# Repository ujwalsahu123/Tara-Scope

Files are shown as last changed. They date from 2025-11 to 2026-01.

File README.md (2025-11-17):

# Stargazer
Just for fun .

most people are too buys in this world and they dont see up the sky , ignore the true reality . 
i felt the same and dived into whats beyond the sky , wanna make something to solve the problem i faced . 
as a beginner in stargazing its very hard to do it . 
there is no cheap and quick thing which can be infomative and fun . 
sterallium and night sky are great , but they are not enough . 

The stargazer is device which uses a green laser to point to any celestial object selected by the user. you just need to install stellarium and select an object . the device will automatically point the lazer to it . dosent matter what your location , time , device orientation is .             (credits-jjrobots) 
Its small , cheap and can unlock the universe for you .

An automatic stargazing device is a tool that helps you easily find and track stars and other celestial objects. It uses motors to move a laser pointer or telescope to the exact position of a star based on your location and the current time. Sensors on the device ensure accurate pointing and tracking, so you can enjoy a clear view of the night sky without manually searching for objects.
<hr>
IDEA DEMO Video : <br>
https://youtube.com/shorts/w3IwdKpvQVA?si=-Li4YI_Lc3XkKAI4   <br>
https://youtu.be/OUAh3qONevA?si=fbP-pA_Mn6YwoY1l      
<hr>
i will try to post the updates (as files) . 

@ components -
arduino uno
stepper motor & drivers *3
bmp module 
mpu9250 
lazer pointer 

@ working -

   Input Location:
You start by inputting your location's latitude, longitude, and altitude into the system. This information helps the device understand where you are on Earth.
   
   Calculate Star Position:
The device uses astronomical algorithms to calculate the current position of the star you want to observe. It considers the date, time, and your location to determine the star's azimuth (horizontal angle) and altitude (vertical angle) in the sky.

  Sensor Data:
The stargazer uses an MPU9250 sensor, which has a magnetometer, gyroscope, and accelerometer. These sensors help determine the device's orientation (roll, pitch, and yaw) in real-time.

  Motor Control:
The device has two stepper motors:
One motor adjusts the azimuth (horizontal angle).
The other motor adjusts the altitude (vertical angle).
The motors move the laser pointer or telescope until the sensor readings match the calculated azimuth and altitude for the target star.
(using 3rd motor for z axis will also be great , but its not mandatory) . 

  Automatic Alignment:
The device uses the sensor data to continuously adjust the motors and keep the pointer aligned with the star. This ensures that the star remains in view, even if there are slight movements or changes.

check out this youtube website related to the project 
https://youtu.be/4PSazYw4XaM?si=X3MrnupO3QnW7joi
iit guy vedio link . 
ardunio project website link.

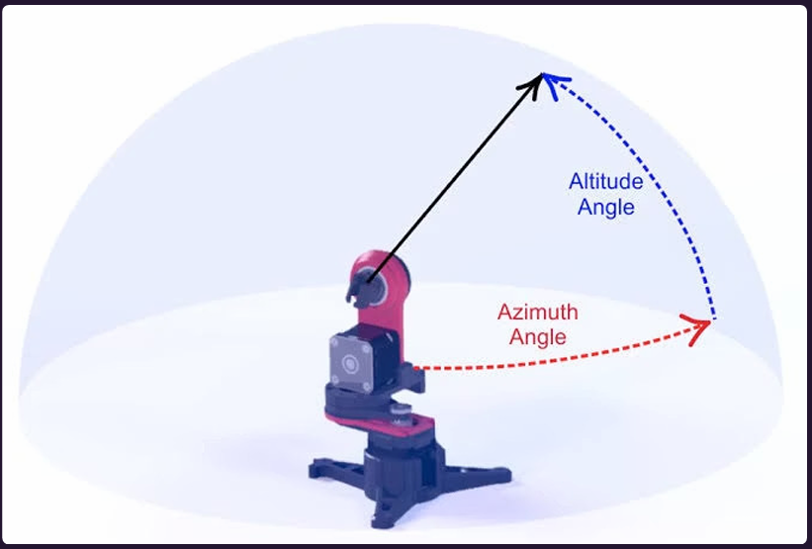
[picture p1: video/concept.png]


archives :
 
Hi guys , i am ujwal sahu , 21 yrs old , studying bachelors in AI form india   .
i am a beginner in stargazing and i was also making the same project as the startracker (the laser one) that you guys are making . 

I red the ( new version of startracker page) blog and its nice .
I think that the vision is exciting and creating a device which connect the space with a beginner with zero friction and affordability is great , though i think you guys are not headed in the right direction . 

lets talk from the bottom up - There are many many people who want to know about the space and not just fiction movies but really want to know about the reality of this world and who we are (not just the daily life we live ) . people forget that we live on a circular planet and there are millions of those and many other exciting things beyond the sky .  mostly every kid wants to become a astronaut , and they are super excited to explore this mysterious world but most dreams die because there is no one to tell them about these things . i myself when wanted to explore the sky , do stargazing , know about the stars above me - it was very difficult , a telescope is very expensive to buy and then also you have to learn about all the stargazing things . i had a green laser so i used to point to the stars and it made me feel like i have the power to touch the stars using the laser . i explored more and got to know about stellarium app and it was really helpful for me to do stargazing and i pointed my laser to the star using that and then i thought to make it automatic => so a device which can directly point to the star that are above me right now and also give me informoation about that and  hence now i am making that device . 
(tip - for sensor using mpu9250 is better , and all 3 axis matters ( yaw ,pitch ,roll) ).

Now if we take a step back and look then this device sucks ( a laser , are you serious ! , it can be illegal ) . and thats why you guys pivoted and made the starpointer form a laser pointing device to a mount for astrophotography  and thats why i said that you guys were not headed in the right direction . 

I think there is a real gap between the consumer who wants to do stargazing and unlock the universe .  
i know stellarium solves this problem , but still i dont think it connects people and excite them . it doesnt  provide much information and its not frictionless , etc . 
I dont know what to make which can solve this gap , which will be a great product . ( making a goto mount with cheap telescope and a better ai guide app which can walk you though the sky thats above you right now and tell facts and exciting thing about the objects and in the same time pointing the telescope to that object .   like a real human stargazing guide ) .  

I want to deep dive in this problem and i want to make something great .
i want to work with you guys .

please share your thoughts on this . 
Thank you .

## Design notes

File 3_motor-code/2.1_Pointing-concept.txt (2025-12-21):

// so we want to make a .ino code which takes alt az and moves motor to achive the RPY to ALt Az. 
// 2 din ka kam hai . - just use the SF code & the logic part sooch lay of how pointing and motor movement ( parallel ) ,  etc stuff ...  and mix karde 
// and then test out karle -> Run the ai_guide wala code to get the alt az and send alt az to arduino (manually) . and see the pointing accracy / error. 

0. make the flowchart - after reading this full info , and old code downside.
1. get the sf_code.ino (which geives the RPY using raw values)
2 see below code for knowing the logic of pointing. (alt az ayga , alt_higher = alt + 0.1 , alt_lower = alt - 0.1 , ..   use delay_speed for faster and slower range )
3 do it for 2 motors ( think how - parallel kaise hoga ?  - read - then motor1 - then motor2 - read .   or like - read - non blocking motor1, ... ? idk )
4 also the SF part is time taking so - we can run the SF code in the Parallel, and just read the latest value and move the motors as per that. 

default function - when pressed 0 or 0 0 then it goes to 0 position. 
// or we can do like - it points and after both motors reached - it calls the laser (fade) and then after laser turned off it goes to default mode and points - 0 , 0 
// and after another alt az we get - it points - turns on laser - comes back to 0,0 .

// basically - we use the SF_code.ino for getting the Rpy from sensor . and we use the Pointing_concept -> which is ek ALT Az diya jaygaa
// and arduino has to catch it. and then range -> Alt_low , Alt_high. and then there is a logic -> read the Pitch and if pitch < Alt_low then move ALT motor clockwise until 
// its in range. so basically the motor move until it reach the target posi. 
// and there are other stuff like - move 1 step when closer , and parallel move both the motors and etc stuff - Run the RPY in parallel function , and in the main function just get the RPY value and make the motors move as per that . 
// or write the RPY calculation function in the main code . idk which is better. need to think.  

// so the Full-motor-code has 2 parts -> SF part . and logic part. 
// the logic part is given below - in flowchart. 
// the SF part is v.imp . so write a SF_code.ino - which simply gets the raw sensors values and does SF and gives RPY. 

Checkout the Arduino.txt file - it has some logic. ..... *******************

// also need to think when will the laser be on -> after target reached , or when pressed space.

// if near then less step move , if far then more step move.
// and it contineaouly iterates .

// and its like a range - (it dosent directly point to 0 deg)
// its like we move the motor to run till it achives a range of (-0.1 to 0.1)

// parallel how motor...

// i think we need to manually hardcode the offset values of mag in the .ino code - after doing mag calib. 
// and acc , gyro ka too direct hardcoded rahega. 

// motor concept -> 

// Alt Az ayga , and the range will become 
// int range = 0.1
// ALT_LOWER =  ALT - range
// ALT_UPPER =  ALT + range
// AZ_LOWER =  AZ - range
// AZ_UPPER =  AZ + range

// so if the ALT = 45.5 then the rangle will be 45.4 to 45.6. and if the sensor pitch is beween that range then it will not move.

// and after the both the targed range is achieved , the laserfade() function will be called to turn on the laser.

// entire flow likh ------------------------------------------
# ..... read sensor ,  parallel motor move , laser point , ......

contineaouly RPY print hoga in terminal so i can know . 

// for parallel motor movement - use cheapstepper ka .newmove(step) function . which is a non-blocking function. 

so  -> loop{

    read sensr value and use SF to get RPY

    if (pitch > alt_higer)
        motorA.newmove(1)
    else if (pitch < alt_lower)
        motorA.newmove(-1)
    else
        motorA.newmove(0)
    
    same for yaw.

    .run()
}

// so it reads RPY then both motors by one step. 

// so here again and again if we read the RPY after every loop then not good. 
// insted we can make another function paralley to calculate RPY. 
// idk if this is good or bad. need to think . since this above code is also looks good. 

old code - MPU wala ---------------------------------------------------------------------------------------

#include <Wire.h>
#include <MPU6050_6Axis_MotionApps20.h>
#include <AccelStepper.h>

// Motor Pins for ULN2003 driver
#define IN1 2
#define IN2 3
#define IN3 4
#define IN4 5

// Target Roll Range
#define TARGET_MIN_ROLL 0.0  // Minimum acceptable roll value
#define TARGET_MAX_ROLL 10.0  // Maximum acceptable roll value

// Speed Adjustment Variables
#define NORMAL_SPEED 400        // Normal speed when roll is far from target range
#define FIRST_SLOW_RANGE 20.0   // Range for slower speed (20 degrees)
#define FIRST_SLOW_RANGE_VAL 10 // Speed value for first slow range
#define SECOND_SLOW_RANGE 10.0  // Range for very slow speed (10 degrees)
#define SECOND_SLOW_RANGE_VAL 2 // Speed value for second slow range

// Initialize stepper motor and MPU
AccelStepper stepper(AccelStepper::FULL4WIRE, IN1, IN3, IN2, IN4);
MPU6050 mpu;

// Global variables
bool dmpReady = false;
uint8_t devStatus;
uint16_t packetSize;
uint8_t fifoBuffer[64];
float currentRoll = 0.0;

// Initialize MPU and Stepper
void setup() {
  Serial.begin(115200);
  Wire.begin();

  // MPU setup
  mpu.initialize();
  devStatus = mpu.dmpInitialize();
  if (devStatus == 0) {
    mpu.setDMPEnabled(true);
    dmpReady = true;
    packetSize = mpu.dmpGetFIFOPacketSize();
    Serial.println("DMP initialized successfully");
  } else {
    Serial.print("DMP initialization failed with code ");
    Serial.println(devStatus);
  }

  // Stepper motor setup
  stepper.setMaxSpeed(1000); // Set maximum motor speed
  stepper.setSpeed(NORMAL_SPEED);     // Set initial motor speed
}

// Function to read roll from MPU6050
void readRoll() {
  if (!dmpReady) return;

  // Check if there's data available in the FIFO buffer
  while (mpu.getFIFOCount() >= packetSize) {
    mpu.getFIFOBytes(fifoBuffer, packetSize);

    Quaternion q;
    VectorFloat gravity;
    float ypr[3];  // Array to hold yaw, pitch, and roll values
    mpu.dmpGetQuaternion(&q, fifoBuffer);
    mpu.dmpGetGravity(&gravity, &q);
    mpu.dmpGetYawPitchRoll(ypr, &q, &gravity);

    // Convert roll to degrees
    currentRoll = ypr[2] * 180.0 / PI;  // ypr[2] is the roll value
  }
}

// Function to adjust motor direction and speed based on roll
void adjustMotorToRollRange() {
  if (currentRoll < TARGET_MIN_ROLL - FIRST_SLOW_RANGE || currentRoll > TARGET_MAX_ROLL + FIRST_SLOW_RANGE) {
    // Roll is far from target range, normal speed (400)
    stepper.setSpeed(currentRoll < TARGET_MIN_ROLL ? NORMAL_SPEED : -NORMAL_SPEED); // Normal speed
    Serial.print("Roll: ");
    Serial.print(currentRoll);
    Serial.println(" (Normal Speed)");
  } else if (((currentRoll >= (TARGET_MIN_ROLL - FIRST_SLOW_RANGE)) && (currentRoll < (TARGET_MIN_ROLL - SECOND_SLOW_RANGE))) ||
             ((currentRoll > (TARGET_MAX_ROLL + SECOND_SLOW_RANGE)) && (currentRoll <= (TARGET_MAX_ROLL + FIRST_SLOW_RANGE)))) {
    // Roll is closer to target range, medium speed (10)
    stepper.setSpeed(currentRoll < TARGET_MIN_ROLL ? FIRST_SLOW_RANGE_VAL : -FIRST_SLOW_RANGE_VAL); // Medium speed
    Serial.print("Roll: ");
    Serial.print(currentRoll);
    Serial.println(" (Medium Speed)");
  } else if (((currentRoll >= (TARGET_MIN_ROLL - SECOND_SLOW_RANGE)) && (currentRoll <= TARGET_MIN_ROLL))  ||
             ((currentRoll <= (TARGET_MAX_ROLL + SECOND_SLOW_RANGE)) && (currentRoll >= TARGET_MAX_ROLL))) {
    // Roll is very close to the target range, very slow speed (1)
    stepper.setSpeed(currentRoll < TARGET_MIN_ROLL ? SECOND_SLOW_RANGE_VAL : -SECOND_SLOW_RANGE_VAL); // Very slow speed
    Serial.print("Roll: ");
    Serial.print(currentRoll);
    Serial.println(" (Very Slow Speed)");
  } else {
    // Roll is within target range, stop motor
    stepper.setSpeed(0); // Stop
    Serial.print("Roll: ");
    Serial.print(currentRoll);
    Serial.println(" (Stop)");
  }
}

// Main loop
void loop() {
  // Continuously read roll from MPU
  readRoll();

  // Adjust motor movement based on roll
  adjustMotorToRollRange();

  // Run the motor at the determined speed
  stepper.runSpeed();
}

---------------------------------------------------------------------------------------
ok so in the above code i had use mpu sensor , and fastaccel code , but  i next time i want to use some other sensor , but this concept of the code is very important . so can you please remove all the mpu sensor part . and instead you can leave a comment like get yaw data .... etc . 

(so here , its the logic code , wihout the mpu par )

#include <AccelStepper.h>

// Motor Pins for ULN2003 driver
#define IN1 2
#define IN2 3
#define IN3 4
#define IN4 5

// Target Roll Range
#define TARGET_MIN_ROLL 0.0  // Minimum acceptable roll value
#define TARGET_MAX_ROLL 10.0 // Maximum acceptable roll value

// Speed Adjustment Variables
#define NORMAL_SPEED 400        // Normal speed when roll is far from target range
#define FIRST_SLOW_RANGE 20.0   // Range for slower speed (20 degrees)
#define FIRST_SLOW_RANGE_VAL 10 // Speed value for first slow range
#define SECOND_SLOW_RANGE 10.0  // Range for very slow speed (10 degrees)
#define SECOND_SLOW_RANGE_VAL 2 // Speed value for second slow range

// Initialize stepper motor
AccelStepper stepper(AccelStepper::FULL4WIRE, IN1, IN3, IN2, IN4);

// Global variables
float currentRoll = 0.0; // Variable to store the roll value

// Initialize Stepper
void setup() {
  Serial.begin(115200);

  // Stepper motor setup
  stepper.setMaxSpeed(1000); // Set maximum motor speed
  stepper.setSpeed(NORMAL_SPEED); // Set initial motor speed

  Serial.println("System initialized. Waiting for sensor data...");
}

// Function to update the roll value
void updateRoll() {
  // Replace the following line with the logic to get roll (or yaw) data from your sensor
  // Example: currentRoll = getYawFromSensor(); or currentRoll = readSensorRoll();
  // Ensure the roll value is in degrees.
  
  // Placeholder for testing
  currentRoll = random(-30, 30); // Replace with actual sensor logic
}

// Function to adjust motor direction and speed based on roll
void adjustMotorToRollRange() {
  if (currentRoll < TARGET_MIN_ROLL - FIRST_SLOW_RANGE || currentRoll > TARGET_MAX_ROLL + FIRST_SLOW_RANGE) {
    // Roll is far from target range, normal speed
    stepper.setSpeed(currentRoll < TARGET_MIN_ROLL ? NORMAL_SPEED : -NORMAL_SPEED);
    Serial.print("Roll: ");
    Serial.print(currentRoll);
    Serial.println(" (Normal Speed)");
  } else if (((currentRoll >= (TARGET_MIN_ROLL - FIRST_SLOW_RANGE)) && (currentRoll < (TARGET_MIN_ROLL - SECOND_SLOW_RANGE))) ||
             ((currentRoll > (TARGET_MAX_ROLL + SECOND_SLOW_RANGE)) && (currentRoll <= (TARGET_MAX_ROLL + FIRST_SLOW_RANGE)))) {
    // Roll is closer to target range, medium speed
    stepper.setSpeed(currentRoll < TARGET_MIN_ROLL ? FIRST_SLOW_RANGE_VAL : -FIRST_SLOW_RANGE_VAL);
    Serial.print("Roll: ");
    Serial.print(currentRoll);
    Serial.println(" (Medium Speed)");
  } else if (((currentRoll >= (TARGET_MIN_ROLL - SECOND_SLOW_RANGE)) && (currentRoll <= TARGET_MIN_ROLL))  ||
             ((currentRoll <= (TARGET_MAX_ROLL + SECOND_SLOW_RANGE)) && (currentRoll >= TARGET_MAX_ROLL))) {
    // Roll is very close to the target range, very slow speed
    stepper.setSpeed(currentRoll < TARGET_MIN_ROLL ? SECOND_SLOW_RANGE_VAL : -SECOND_SLOW_RANGE_VAL);
    Serial.print("Roll: ");
    Serial.print(currentRoll);
    Serial.println(" (Very Slow Speed)");
  } else {
    // Roll is within target range, stop motor
    stepper.setSpeed(0);
    Serial.print("Roll: ");
    Serial.print(currentRoll);
    Serial.println(" (Stop)");
  }
}

// Main loop
void loop() {
  // Continuously update roll value from the sensor
  updateRoll();

  // Adjust motor movement based on roll
  adjustMotorToRollRange();

  // Run the motor at the determined speed
  stepper.runSpeed();
}

---------------------------------------------------------------------------------------
ok now can you make this same conectp and code for cheapstepper library instead of fastaccell

(so now gpt gave the code using cheapstepper.) but the logic can be imporved
instead of using the Rpm(speed) , we can move 1 step at a time and we will play with the delay speed . 
to make the speed - fast / slow . 

#include <CheapStepper.h>

// Motor Pins for ULN2003 driver
#define IN1 2
#define IN2 3
#define IN3 4
#define IN4 5

// Target Roll Range
#define TARGET_MIN_ROLL 0.0  // Minimum acceptable roll value
#define TARGET_MAX_ROLL 10.0 // Maximum acceptable roll value

// Speed Adjustment Variables
#define NORMAL_DELAY 2        // Normal speed delay (lower value = faster speed)
#define FIRST_SLOW_DELAY 10   // Medium speed delay
#define SECOND_SLOW_DELAY 30  // Very slow speed delay

// Initialize stepper motor
CheapStepper stepper(IN1, IN2, IN3, IN4);

// Global variables
float currentRoll = 0.0; // Variable to store the roll value
bool motorMoving = false;

// Initialize Stepper
void setup() {
  Serial.begin(115200);

  // Stepper motor setup
  stepper.setRpm(15); // Default RPM (can be adjusted dynamically later)

  Serial.println("System initialized. Waiting for sensor data...");
}

// Function to update the roll value
void updateRoll() {
  // Replace the following line with the logic to get roll (or yaw) data from your sensor
  // Example: currentRoll = getYawFromSensor(); or currentRoll = readSensorRoll();
  // Ensure the roll value is in degrees.

  // Placeholder for testing
  currentRoll = random(-30, 30); // Replace with actual sensor logic
}

// Function to adjust motor direction and speed based on roll
void adjustMotorToRollRange() {
  if (currentRoll < TARGET_MIN_ROLL - 20.0 || currentRoll > TARGET_MAX_ROLL + 20.0) {
    // Roll is far from target range, normal speed
    stepper.setRpm(30); // Set higher RPM for faster movement
    motorMoving = true;
    if (currentRoll < TARGET_MIN_ROLL) {
      stepper.moveDegreesCW(5); // Move clockwise
    } else {
      stepper.moveDegreesCCW(5); // Move counterclockwise
    }
    Serial.print("Roll: ");
    Serial.print(currentRoll);
    Serial.println(" (Normal Speed)");
  } else if (((currentRoll >= (TARGET_MIN_ROLL - 20.0)) && (currentRoll < (TARGET_MIN_ROLL - 10.0))) ||
             ((currentRoll > (TARGET_MAX_ROLL + 10.0)) && (currentRoll <= (TARGET_MAX_ROLL + 20.0)))) {
    // Roll is closer to target range, medium speed
    stepper.setRpm(10); // Set medium RPM for slower movement
    motorMoving = true;
    if (currentRoll < TARGET_MIN_ROLL) {
      stepper.moveDegreesCW(1); // Move clockwise slowly
    } else {
      stepper.moveDegreesCCW(1); // Move counterclockwise slowly
    }
    Serial.print("Roll: ");
    Serial.print(currentRoll);
    Serial.println(" (Medium Speed)");
  } else if (((currentRoll >= (TARGET_MIN_ROLL - 10.0)) && (currentRoll <= TARGET_MIN_ROLL)) ||
             ((currentRoll <= (TARGET_MAX_ROLL + 10.0)) && (currentRoll >= TARGET_MAX_ROLL))) {
    // Roll is very close to the target range, very slow speed
    stepper.setRpm(5); // Set very slow RPM for precise movement
    motorMoving = true;
    if (currentRoll < TARGET_MIN_ROLL) {
      stepper.moveStepsCW(1); // Very slow clockwise movement
    } else {
      stepper.moveStepsCCW(1); // Very slow counterclockwise movement
    }
    Serial.print("Roll: ");
    Serial.print(currentRoll);
    Serial.println(" (Very Slow Speed)");
  } else {
    // Roll is within target range, stop motor
    motorMoving = false;
    Serial.print("Roll: ");
    Serial.print(currentRoll);
    Serial.println(" (Stop)");
  }
}

// Main loop
void loop() {
  // Continuously update roll value from the sensor
  updateRoll();

  // Adjust motor movement based on roll
  adjustMotorToRollRange();

  // Allow the motor to complete the current step if moving
  if (motorMoving) {
    stepper.run();
  }
}

---------------------------------------------------------------------------------------

same as the above code - but for 2 motors - pitch and yaw . 

#include <CheapStepper.h>

// Motor Pins for Pitch (ULN2003 driver)
#define PITCH_IN1 2
#define PITCH_IN2 3
#define PITCH_IN3 4
#define PITCH_IN4 5

// Motor Pins for Yaw (ULN2003 driver)
#define YAW_IN1 6
#define YAW_IN2 7
#define YAW_IN3 8
#define YAW_IN4 9

// Target Ranges
#define TARGET_MIN_PITCH 0.0  // Minimum acceptable pitch value
#define TARGET_MAX_PITCH 10.0 // Maximum acceptable pitch value
#define TARGET_MIN_YAW 0.0    // Minimum acceptable yaw value
#define TARGET_MAX_YAW 10.0   // Maximum acceptable yaw value

// Initialize stepper motors
CheapStepper pitchMotor(PITCH_IN1, PITCH_IN2, PITCH_IN3, PITCH_IN4);
CheapStepper yawMotor(YAW_IN1, YAW_IN2, YAW_IN3, YAW_IN4);

// Global variables for sensor data
float currentPitch = 0.0;
float currentYaw = 0.0;

// Initialize Stepper
void setup() {
  Serial.begin(115200);

  // Motor setup
  pitchMotor.setRpm(15); // Default RPM for pitch motor
  yawMotor.setRpm(15);   // Default RPM for yaw motor

  Serial.println("System initialized. Waiting for sensor data...");
}

// Function to update pitch and yaw values
void updatePitchAndYaw() {
  // Replace these lines with the logic to get pitch and yaw data from your sensor
  // Example: currentPitch = getPitchFromSensor(); currentYaw = getYawFromSensor();

  // Placeholder for testing
  currentPitch = random(-30, 30); // Replace with actual sensor logic
  currentYaw = random(-30, 30);   // Replace with actual sensor logic
}

// Function to adjust pitch motor
void adjustPitchMotor() {
  if (currentPitch < TARGET_MIN_PITCH - 20.0 || currentPitch > TARGET_MAX_PITCH + 20.0) {
    // Far from target range, normal speed
    pitchMotor.setRpm(30);
    if (currentPitch < TARGET_MIN_PITCH) {
      pitchMotor.moveDegreesCW(5); // Move clockwise
    } else {
      pitchMotor.moveDegreesCCW(5); // Move counterclockwise
    }
    Serial.print("Pitch: ");
    Serial.print(currentPitch);
    Serial.println(" (Normal Speed)");
  } else if (abs(currentPitch - TARGET_MIN_PITCH) <= 10.0 || abs(currentPitch - TARGET_MAX_PITCH) <= 10.0) {
    // Close to target range, slow speed
    pitchMotor.setRpm(5);
    if (currentPitch < TARGET_MIN_PITCH) {
      pitchMotor.moveStepsCW(1); // Move very slowly clockwise
    } else {
      pitchMotor.moveStepsCCW(1); // Move very slowly counterclockwise
    }
    Serial.print("Pitch: ");
    Serial.print(currentPitch);
    Serial.println(" (Slow Speed)");
  } else {
    // Within range, stop motor
    Serial.print("Pitch: ");
    Serial.print(currentPitch);
    Serial.println(" (Stop)");
  }
}

// Function to adjust yaw motor
void adjustYawMotor() {
  if (currentYaw < TARGET_MIN_YAW - 20.0 || currentYaw > TARGET_MAX_YAW + 20.0) {
    // Far from target range, normal speed
    yawMotor.setRpm(30);
    if (currentYaw < TARGET_MIN_YAW) {
      yawMotor.moveDegreesCW(5); // Move clockwise
    } else {
      yawMotor.moveDegreesCCW(5); // Move counterclockwise
    }
    Serial.print("Yaw: ");
    Serial.print(currentYaw);
    Serial.println(" (Normal Speed)");
  } else if (abs(currentYaw - TARGET_MIN_YAW) <= 10.0 || abs(currentYaw - TARGET_MAX_YAW) <= 10.0) {
    // Close to target range, slow speed
    yawMotor.setRpm(5);
    if (currentYaw < TARGET_MIN_YAW) {
      yawMotor.moveStepsCW(1); // Move very slowly clockwise
    } else {
      yawMotor.moveStepsCCW(1); // Move very slowly counterclockwise
    }
    Serial.print("Yaw: ");
    Serial.print(currentYaw);
    Serial.println(" (Slow Speed)");
  } else {
    // Within range, stop motor
    Serial.print("Yaw: ");
    Serial.print(currentYaw);
    Serial.println(" (Stop)");
  }
}

// Main loop
void loop() {
  // Continuously update pitch and yaw values
  updatePitchAndYaw();

  // Adjust motor movement based on pitch and yaw
  adjustPitchMotor();
  adjustYawMotor();
}

---------------------------------------------------------------------------------------
---------------------------------------------------------------------------------------
---------------------------------------------------------------------------------------
---------------------------------------------------------------------------------------

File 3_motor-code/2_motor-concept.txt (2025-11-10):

// arduino code.txt may bhi hai ..
// star_pointing gpt chat. 

// if near then less step move , if far then more step move.
// and it contineaouly iterates .

// and its like a range - (it dosent directly point to 0 deg)
// its like we move the motor to run till it achives a range of (-0.1 to 0.1)

// parallel how motor...

// i think we need to manually hardcode the offset values of mag in the .ino code - after doing mag calib. 
// and acc , gyro ka too direct hardcoded rahega. 

// motor concept -> 

// Alt Az ayga , and the range will become 
// int range = 0.1
// ALT_LOWER =  ALT - range
// ALT_UPPER =  ALT + range
// AZ_LOWER =  AZ - range
// AZ_UPPER =  AZ + range

// so if the ALT = 45.5 then the rangle will be 45.4 to 45.6. and if the sensor pitch is beween that range then it will not move.

// and after the both the targed range is achieved , the laserfade() function will be called to turn on the laser.

// entire flow likh ------------------------------------------
# ..... read sensor ,  parallel motor move , laser point , ......

setOutputTorque(true)
Coils stay ON → motor locks position (useful when holding a laser steady) 
? idk to use this.  since we move motors as per sensors (consistently) and not just move some particular step and wait.

// for parallel motor movement - use cheapstepper ka .newmove(step) function . which is a non-blocking function. 

so  -> loop{

    read sensr value and use SF to get RPY

    if (pitch > alt_higer)
        motorA.newmove(1)
    else if (pitch < alt_lower)
        motorA.newmove(-1)
    else
        motorA.newmove(0)
    
    same for yaw.

    .run()
}

// so it reads RPY then both motors by one step. 

// so here again and again if we read the RPY after every loop then not good. 
// insted we can make another function paralley to calculate RPY. 
// idk if this is good or bad. need to think . since this above code is also looks good.

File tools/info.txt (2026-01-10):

TaraScope – Arduino CLI + Python Workflow Notes
==============================================

1) Install Arduino CLI (Windows 64-bit)
---------------------------------------
Download:
https://github.com/arduino/arduino-cli/releases

File:
arduino-cli_1.4.0_Windows_64bit.zip

Extract anywhere (example):
S:\ujwal sahu\Downloads\arduino-cli_1.4.0_Windows_64bit

Add the folder containing:
arduino-cli.exe
to **User Environment Variable → PATH**  (press win -> search Environment variable -> Advance -> Environment variable -> press PATH in user env variable -> Edit -> NEW -> paste the folder path in which .exe file is there -> ok , ok , ok .) ( do like this also next times for adding Env variable and also Restart vs code...)

Verify in CMD / PowerShell:
arduino-cli version

2) Initial Arduino CLI Setup in cmd
----------------------------
Generate config file:
arduino-cli config init

This creates:
C:\Users\<username>\AppData\Local\Arduino15\arduino-cli.yaml

Verify config:
arduino-cli config dump

3) Configure Arduino Libraries Location
---------------------------------------
Edit file:
C:\Users\<username>\AppData\Local\Arduino15\arduino-cli.yaml

Ensure this exists:  (path location in which the arudino libraries are there / so that we use that same libraries here also)
directories:
  user: S:\ujwal sahu\OneDrive\Documents\Arduino     

(This makes Arduino CLI use the SAME libraries as Arduino IDE)

4) Install Board Support in cmd (Arduino Uno / AVR)
--------------------------------------------
Update index:
arduino-cli core update-index

Install AVR core:
arduino-cli core install arduino:avr

5) Verify Arduino Connection in cmd
----------------------------
Plug Arduino Uno

Check port:
arduino-cli board list

Example output:
COM7  serial  Arduino Uno

6) Create upload.bat (Single Universal Uploader)
------------------------------------------------
Location:
TaraScope\tools\upload.bat

(put the parent folder in which the upload.bat is there (aka S:\ujwal sahu\...\TaraScope\tools ) -> to Environment varibale PATH so it can be run from ANY folder)

Usage:
upload uno COM7 115200 file.ino

Supports:
- Any folder
- Any .ino file
- Arduino Uno / Nano / etc
- Compile + Upload + Serial Monitor

7) upload.bat Features
----------------------
- Auto-detect sketch folder
- Fix Arduino requirement:
  (main .ino name == folder name)
- Uses Arduino IDE libraries
- Shows compile errors in terminal
- Opens Serial Monitor automatically

8) Compile + Upload from Anywhere
---------------------------------
Examples:

upload uno COM7 115200 TARA_SCOPE.ino

upload uno COM7 115200
"S:\ujwal sahu\Tara_Scope\1_calibration\4_final\1.1_Auto_calib.ino"

9) Python + Arduino Workflow
----------------------------
- Python sends commands via Serial
- Arduino performs calibration / sensor read
- Python stores results in offsets.txt
- Offsets sent back to Arduino on demand
- No auto-offset on boot (manual trigger with 'g')

10) Important Rules (Very Important)
------------------------------------
- .ino files must contain ONLY valid C/C++ code
- Notes / explanations MUST be in:
  - info.txt
  - README.md
  - comments (// or /* */)
- NEVER paste plain English into .ino without comments
- Arduino CLI is stricter than Arduino IDE

11) Final Command Summary
------------------------
Check version:
arduino-cli version

List boards:
arduino-cli board list

Upload from anywhere:
upload uno COM7 115200 file.ino

Status: ✔ WORKING
-----------------
Arduino CLI + Python + Calibration system is stable.

12) Installing Arduino Libraries (2 Ways)
-----------------------------------------

There are TWO ways to install Arduino libraries.
We are using WAY 1 (recommended).

-----------------------------------------
WAY 1 (Recommended – Uses Arduino IDE)
-----------------------------------------
This is what we are already doing.

Steps:
1. Open Arduino IDE
2. Go to:
   Sketch → Include Library → Manage Libraries
3. Search and install required libraries
   (example: SparkFun ISM330DHCX, CheapStepper, etc.)

Where libraries are stored:
S:\ujwal sahu\OneDrive\Documents\Arduino\libraries

Why this works:
- Arduino IDE and Arduino CLI share the SAME library folder
- No duplicate installs
- No version mismatch
- Arduino CLI automatically finds libraries

✔ This is the BEST and simplest method

-----------------------------------------
WAY 2 (CLI-only Method – Optional)
-----------------------------------------
Use this ONLY if you do NOT have Arduino IDE installed.

Example:
arduino-cli lib update-index
arduino-cli lib install "SparkFun 6DoF ISM330DHCX"
arduino-cli lib install "CheapStepper"

Libraries will still be installed into:
directories.user (from arduino-cli.yaml)

Downside:
- Harder to manage
- Library names must be exact
- Less visual control

-----------------------------------------
How to Verify Library Installation
-----------------------------------------
Run:
arduino-cli lib list

Or check folder:
S:\ujwal sahu\OneDrive\Documents\Arduino\libraries

-----------------------------------------
Important Rules for Libraries
-----------------------------------------
- Do NOT mix multiple library folders
- Do NOT copy libraries manually unless necessary
- Always include headers properly in .ino:
  #include <Wire.h>
  #include <SparkFun_ISM330DHCX.h>
- If compilation fails:
  → Check library name
  → Check library path
  → Check include order

Status:
✔ Library system is correctly configured
✔ Arduino IDE + Arduino CLI are fully synced

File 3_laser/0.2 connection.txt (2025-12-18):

there are many ways to make the LASER DRIVER

we can power the laser - directly by the arduino , or by external power supply - and use LM... to Step down the voltage to 3v or etc as per the laser . 

connetion option 1 -> using relay 

.... we can directly or using LM

......

connection option 2 -> using logic level mosfet

.... driectly or using LM

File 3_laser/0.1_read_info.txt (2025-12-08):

// 1) define the pin number 
// #define LASER_PIN 3, 5, 6, 9, 10, 11 (analog / PWM) 2, 3, 4, 7, 8, 12, 13 (digital)

// 2) in setup - set the pin mode to output . and set it low to start with laser off
// pinMode(LASER_PIN, OUTPUT);
// digitalWrite(LASER_PIN, LOW);

// 3) to turn on the laser at full intensity - set the pin high

//  digitalWrite(LASER_PIN, HIGH);  // (ON) Switch is ON thus the laser is ON (it will be ON until set off)
//  analogWrite(LASER_PIN, 0-255);  // (ON) controlled brightness (use a PWM digital pin) (it will be ON until set off)
//  digitalWrite(LASER_PIN, LOW);   // (OFF) so the Switch is now OFF and thus laser is OFF

// the PWM pins quickly turns the current on and off
// PWM doesn’t actually change the current level — the current is always 0% or 100%. It simply turns the power ON and OFF very quickly (hundreds of times per second), and the ratio of ON vs OFF time makes our eyes perceive different brightness levels.
// 20% duty -> 20% time on , 80% time off 

-----------------------------------------------INFO----------------------------------------------------

UNO vs ESP  - digital pins to use . 

## ⚙️ For **Arduino Uno:**

### 🔹 **Normal ON/OFF (digital control)**

You can use **any digital pin** for this.
✅ Recommended pins:

```
2, 3, 4, 7, 8, 12, or 13
```

➡️ Example:

```cpp
#define LASER_PIN 7
```

and use `digitalWrite(LASER_PIN, HIGH/LOW)` for full ON/OFF control.

---

### 🔸 **Brightness Control (PWM mode)**

PWM = analog-style brightness via fast ON/OFF switching.
Only certain pins on the Uno support this.

✅ PWM-capable pins:

```
3, 5, 6, 9, 10, 11
```

➡️ Example:

```cpp
#define LASER_PIN 9
```

and use `analogWrite(LASER_PIN, value);`
where `value` ranges from **0 (off)** to **255 (full brightness)**.

---

### ⚠️ **Note**

* The PWM pins usually have a **“~” (tilde symbol)** next to them on your Arduino board.
* Don’t use the same pin for both functions at once — just pick **one**:

  * Pin 7 → simple ON/OFF
  * Pin 9 → brightness control

---

Would you like me to show you how to make the **brightness change smoothly (fade in/out)** — like a laser pulsing effect?

How does the Switing on and off works . 
---

### 🌟 Think of it like a light switch

Your laser needs **electricity to flow** from the battery’s + (positive) to – (negative).
If the path is complete → **laser ON**
If the path is broken → **laser OFF**

---

### ⚡ What the MOSFET does

The **MOSFET in your D4184** is like an **automatic switch** placed on the **negative (–)** side of the laser.

So:

* The **+ (positive)** of the laser is *always connected* to power.
* The **– (negative)** wire of the laser goes *through* the MOSFET — it decides whether the laser can connect to ground or not.

---

### 🧠 When the Arduino sends a signal

| Arduino Signal | What the D4184 does | What happens |
| --- | --- | --- |
| **LOW (0V)** | The switch (MOSFET) is **open** | No current can flow → ❌ Laser OFF |
| **HIGH (5V or 3.3V)** | The switch **closes** | Current flows → ✅ Laser ON |

---

### 💡 Simple flow of current

When **ON**:

```
+ (Power Bank → LM2596) → Laser → MOSFET (closed switch) → Ground
```

When **OFF**:

```
+ (Power Bank → LM2596) → Laser → (open switch ❌) → No Ground
```

No ground = no current = no light.

---

### 🎛️ The Arduino’s job

Your Arduino doesn’t power the laser directly.
It just sends a **tiny control signal** (like your finger flipping a switch) to the D4184 module.
The D4184 then handles the **actual laser current** safely.

---

### ⚙️ Summary in one line:

> Arduino tells the MOSFET when to connect the laser’s negative wire to ground.
> When connected → current flows → laser ON
> When disconnected → no current → laser OFF

---

Would you like me to add one small sketch (hand-drawn style) showing this visually — current flow ON vs OFF? It makes it *click instantly.*

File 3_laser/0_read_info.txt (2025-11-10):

// 1) define the pin number 
// #define LASER_PIN 7

// 2) in setup - set the pin mode to output . and set it low to start with laser off
// pinMode(LASER_PIN, OUTPUT);
// digitalWrite(LASER_PIN, LOW);

// 3) to turn on the laser at full intensity - set the pin high

//  digitalWrite(LASER_PIN, HIGH);  // (ON) Switch is ON thus the laser is ON (it will be ON until set off)
//  analogWrite(LASER_PIN, 0-255);  // (ON) controlled brightness (use a PWM digital pin) (it will be ON until set off)
//  digitalWrite(LASER_PIN, LOW);   // (OFF) so the Switch is now OFF and thus laser is OFF

#define LASER_PIN 7   // D41 PWM input pin

void setup() {
  pinMode(LASER_PIN, OUTPUT);
  digitalWrite(LASER_PIN, LOW);   // Start with laser off
}

void loop() {
  digitalWrite(LASER_PIN, HIGH);  // switch is turned on , thus Laser ON (full intensity)
  delay(2000);                    // Keep ON for 2 seconds
  digitalWrite(LASER_PIN, LOW);   // Laser OFF
  delay(2000);                    // Keep OFF for 2 seconds
}

#define LASER_PIN 9   // Use a PWM-capable pin (e.g., 3, 5, 6, 9, 10, or 11 on UNO)

void setup() {
  pinMode(LASER_PIN, OUTPUT);
}

void loop() {
  analogWrite(LASER_PIN, 255);  // 100% brightness (full ON)
  delay(2000);

  analogWrite(LASER_PIN, 128);  // 50% brightness
  delay(2000);

  analogWrite(LASER_PIN, 64);   // 25% brightness
  delay(2000);

  analogWrite(LASER_PIN, 0);    // 0% brightness (OFF)
  delay(2000);
}

UNO vs ESP  - digital pins to use . 

## ⚙️ For **Arduino Uno:**

### 🔹 **Normal ON/OFF (digital control)**

You can use **any digital pin** for this.
✅ Recommended pins:

```
2, 3, 4, 7, 8, 12, or 13
```

➡️ Example:

```cpp
#define LASER_PIN 7
```

and use `digitalWrite(LASER_PIN, HIGH/LOW)` for full ON/OFF control.

---

### 🔸 **Brightness Control (PWM mode)**

PWM = analog-style brightness via fast ON/OFF switching.
Only certain pins on the Uno support this.

✅ PWM-capable pins:

```
3, 5, 6, 9, 10, 11
```

➡️ Example:

```cpp
#define LASER_PIN 9
```

and use `analogWrite(LASER_PIN, value);`
where `value` ranges from **0 (off)** to **255 (full brightness)**.

---

### ⚠️ **Note**

* The PWM pins usually have a **“~” (tilde symbol)** next to them on your Arduino board.
* Don’t use the same pin for both functions at once — just pick **one**:

  * Pin 7 → simple ON/OFF
  * Pin 9 → brightness control

---

Would you like me to show you how to make the **brightness change smoothly (fade in/out)** — like a laser pulsing effect?

How does the Switing on and off works . 
---

### 🌟 Think of it like a light switch

Your laser needs **electricity to flow** from the battery’s + (positive) to – (negative).
If the path is complete → **laser ON**
If the path is broken → **laser OFF**

---

### ⚡ What the MOSFET does

The **MOSFET in your D4184** is like an **automatic switch** placed on the **negative (–)** side of the laser.

So:

* The **+ (positive)** of the laser is *always connected* to power.
* The **– (negative)** wire of the laser goes *through* the MOSFET — it decides whether the laser can connect to ground or not.

---

### 🧠 When the Arduino sends a signal

| Arduino Signal | What the D4184 does | What happens |
| --- | --- | --- |
| **LOW (0V)** | The switch (MOSFET) is **open** | No current can flow → ❌ Laser OFF |
| **HIGH (5V or 3.3V)** | The switch **closes** | Current flows → ✅ Laser ON |

---

### 💡 Simple flow of current

When **ON**:

```
+ (Power Bank → LM2596) → Laser → MOSFET (closed switch) → Ground
```

When **OFF**:

```
+ (Power Bank → LM2596) → Laser → (open switch ❌) → No Ground
```

No ground = no current = no light.

---

### 🎛️ The Arduino’s job

Your Arduino doesn’t power the laser directly.
It just sends a **tiny control signal** (like your finger flipping a switch) to the D4184 module.
The D4184 then handles the **actual laser current** safely.

---

### ⚙️ Summary in one line:

> Arduino tells the MOSFET when to connect the laser’s negative wire to ground.
> When connected → current flows → laser ON
> When disconnected → no current → laser OFF

---

Would you like me to add one small sketch (hand-drawn style) showing this visually — current flow ON vs OFF? It makes it *click instantly.*

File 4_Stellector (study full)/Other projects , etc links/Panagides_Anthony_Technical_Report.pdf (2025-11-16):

Mountain Directed Energy Wayfinder (D.E.W.)

### A Technical Report submitted to the Department of Electrical and Computer Engineering

### Presented to the Faculty of the School of Engineering and Applied Science

### University of Virginia • Charlottesville, Virginia

### In Partial Fulfillment of the Requirements for the Degree

### Bachelor of Science, School of Engineering

Anthony Panagides

### Fall 2023

### Technical Project Team Members

### Jeffrey Grow

### Kieran Lynch

### Errick Mah

### Daniel Xue

On my honor as a University Student, I have neither given nor received unauthorized aid on this

### assignment as defined by the Honor Guidelines for Thesis-Related Assignments

### Adam Barnes, Department of Electrical and Computer Engineering

# Mountain Directed Energy Wayfinder (D.E.W.)

PEPCISco

### 5 December 2023

Jeffrey Grow, Kieran Lynch, Errick Mah, Anthony Panagides, Daniel Xue

On my honor, I pledge that I have neither given nor received help on this assignment.

Abstract—This project created a device that automatically locates various celestial objects with a laser pointer. An STM32-controlled gimbal points the laser at the selected celestial object using data from a GNSS module. Groups of amateur astronomers are the target market for this device. The device utilizes battery to supply power to operate in locations where AC wall power is not available. Additionally, the costliness of extant devices is bypassed by the relatively inexpensive cost estimate of the device at ≈$250.

CONTENTS

I | Statement of Work | 2
II | Background | 2
III | Societal Impact Constraints | 3
III-A | Environmental Impact | | 3
III-B | Health and Safety | | 3
III-C | Public Policy | | 3
III-D | Ethical Concerns | | 3
III-E | Stakeholder Considerations | | 4
IV | Physical Constraints | 4
IV-A | Part Availability and Manufacturability . | 4
V | External Standards | 4
VI | Intellectual Property Issues | 4
VI-A | Claimed Invention | | 4
VI-B | 35 U.S.C 101 | | 5
VI-C | 35 U.S.C. 102 | | 5
VI-D | 35 U.S.C. 103 | | 6
VI-E | Allowable Subject Matter | | 6
VI-E1 | Hardware Subject Matter . . | 6
VI-E2 | Software Subject Matter . . . | 6
VI-F | Software License Agreements | | 7
VII | Project Description | 7
VII-A | Objectives | | 7
VII-B | Functionality | | 7
VII-C | Technical Considerations | | 7
VII-D | Design Challenges | | 9
VII-E | Test Plan | | 9
VII-F | Resources & Equipment | | 10
VII-G | Software | | 10
VIII Timeline | 10
IX | Costs | 13
IX-A | Single Unit | | 14
IX-B | Mass Production | | 14
X | Final Results | 14
X-A | Power | | 14
X-B | Laser | | 14
X-C | PCB | | 14
X-D | Gimbal | | 14
X-E | User Interface | | 14
X-F | GPS | | 15
X-G | Calibration | | 15
X-H | Pointing | | 15
X-I | System | | 15
X-J | Total | | 15
XI | Future Work | 15
XI-A | Portability | | 15
XI-B | GNSS Functionality | | 16
XI-C | Gearing System | | 16
XI-D | Improved System Calibration | | 16
References | 16
Appendix | 18
A | Initial Budget Used | | 18
B | Additional Budget Used | | 19

LIST OF FIGURES

1 | Block Diagram - Power Flow, Data Transfer . . | 7
2 | Pitch and Yaw Definition | | 8
3 | Initial timeline for project proposal, design, and
| component orders | | 11
4 | Final timeline for initial presentation, project
| proposal, poster session | | 11
5 | Final timeline for midterm design review, design,
| and component orders | | 12
6 | Initial timeline for assembly, testing, second de-
| sign iteration, final report, and demo | | 12
7 | Final timeline for assembly, subsystem testing,
| and integration | | 13
8 | Final timeline for system testing, field testing,
| and demo | | 13

LIST OF TABLES

I | Standards and Regulations | | 5
II | Costs Summarized | | 14
III | Mountain DEW Final Prototype Point Allotment | 15
IV | Mountain DEW Final Prototype Grading Scale . | 15
I. STATEMENT OF WORK

Jeffrey Grow contributed printed circuit board (PCB) design, manufacturing, and testing. This included the initial schematic capture as well as PCB layout, both of which were completed in the KiCad software. As part of this, he was also responsible for the setup of a repository for the PCB files so all group members would be able to access them from their own computers. He integrated the power supply design from E.M. as well as the pinouts from D.X. into the circuit schematic. Once the PCBs were laid out and ordered, he assisted E.M. with the soldering of the through-hole electrical components. After that, he tested the PCBs to ensure that all functionality was met. Additionally, he worked on the testing environment and found suitable electrical components for the PCBs that met the design requirements.

Kieran Lynch contributed the design and production of all mechanical components of the gimbal. This included the mount for the tripod and all the housing for the electronics. This also included the gimbal itself and the laser holder. The design process included creating a 3D model accounting for the size of various components to allow for press fits where ever possible. The production process consisted of plastic selection and ensuring that the 3D printing process worked without issue. Additionally, he worked on construction of a testing environment with E.M. and soldering with E.M. and J.G.

Errick | Mah | contributed | buck | converter | design | and
specifications, including component selection and layout recommendations, according to the associated datasheet and application notes for each chip buck converter. Design of the power supply circuitry was tested alongside in tandem with J.G. and assembly of a testing environment for a final prototype was performed alongside D.X. and K.L. in order to adequately demonstrate the functionality of the project. Also contributed were general administration and logistical management for this project, including scheduling and budgetary concerns; group assignment submissions relevant to the coursework associated with this project, such as reports, presentations, and when within the allotted budget, parts orders; and workspace organization, material acquisition, and itemization. He has also contributed a knowledge of engineering standards and intellectual property to the considerations made for this project.
Anthony | Panagides | contributed | to | the | design | and
implementation of the embedded software. This includes the calculations for directing the laser towards targets in the night and attempting to integrate global navigation satellite system (GNSS) signals into the software. Produced visuals and diagrams for use in presentations and poster session. He also worked with TouchGFX’s model-view-presenter framework to test the LCD’s operation and create the device’s user interface. He also storyboarded, directed, recorded, and edited the group’s Final Video, in addition to helping to purchase and organize components for the team.

Daniel Xue contributed the design and implementation of the device’s LCD user interface and embedded software for controlling the laser and motors. This includes the generation of a software flowchart matching each screen within TouchGFX’s model-view-controller (MVC) framework to appropriate functions of the laser and motors, as well as the creation of software for calculating the azimuth and elevation values for each star given its right-ascension and declination coordinates, the user’s latitude and longitude, and the time of day. Also contributed were appropriate documentation of the use of digital input/output pins on the STM32 board for each of the major hardware components, as well as notes on the position and orientation of wires and other connectors between each major component on the final device. He also designed all elements of the input, calibration, and star select menus, including wildcards, tick-based events, and other images. The test chamber’s upper supports and its demo targets were also contributed by Daniel, in collaboration with E.M.

II. BACKGROUND

For groups of amateur astronomy enthusiasts, stargazing for the first time can be challenging due to (1) low-light conditions that prevent the easy use of paper guides and
(2) lack of wall-power and cell-signals that may limit the use of mobile phones and other smart devices in the remote locations ideal for stargazing. While having a more experienced stargazer present can help resolve these issues, it can often be challenging to direct everyone’s attention to the same point in the sky with only one’s arm or a flashlight, especially for larger stargazing groups. Because of this, there is a need for automated star-tracking systems for such groups.

Commercial systems that track stars already exist. However, although the systems themselves are only around $100, these systems only work with telescopes costing upwards of $1000 [1]. A common budget option is simply to have someone knowledgeable about the locations and positions of stars use a laser pointer to point out stars. This is in fact so common that there is an entire market dedicated to providing lasers for this application [2]. The goal of this project will be to combine these extremes to create an affordable option for those who may not already know someone with stargazing experience.

There are multiple relevant courses to this project, including the ECE Fundamentals series (ECE 2630, ECE 2660, ECE 3750), Electromagnetic Energy Conversion (ECE 3250), Introduction to Embedded Systems (ECE 3430), Optics and Lasers (ECE 5241), Introduction to Control Systems (ECE 6850), and Computer Networks (ECE 4457). The ECE Fundamentals series helps with the power board design as it was the class where basic circuit analysis, layout, and manufacturing are discussed. ECE 3250 was relevant to the design and implementation of the buck converters. The Introduction to Embedded class assisted with an understanding of the STM32 programming and system design, as microcontrollers were the focus of the class. The Optics and Lasers class was useful for understanding the structure of lasers. Intro to Controls Systems provides a better understanding the motor drivers and their constraints. Initially, it was believed that the Computer Networks course would be useful for parsing and manipulating the data sent to and from the GPS module for calibrating and adjusting the last pointer. However, in the course of the development of the embedded software, it was determined that the GNSS module was not a necessary inclusion in order to satisfy the metric of a minimum viable product.

III. SOCIETAL IMPACT CONSTRAINTS

A. Environmental Impact
Directing lasers to the sky may have an impact on wildlife, particularly migratory birds, as research conducted by the U.S. Department of Agriculture has shown that low-to-moderate power lasers from classes 2 to 3 can disperse bird species under low-light conditions, albeit at no significant harm to the species [3]. This has been leveraged through the creation of laser bird deterrent devices, such as the Agrilaser Autonomic, which uses a higher power laser (Class 3B) for the task of long-range bird deterrence [4]. This effect was not observed for deer using green and blue lasers of a similar level of power [5]; however, suggesting that the laser star finder’s environmental impact could be mitigated through systems that detected moving targets in the device’s field of view and steered the laser away from targets that were not found to be in the sky.

From a device lifetime standpoint, the materials used to construct the device have an environmental impact, as the process for producing the parts for the device requires some level of electrical power and plastics, both of which contribute to the release of greenhouse gasses in the atmosphere. As the device is intended to function in largely remote areas, it runs on batteries and other electrical components that need to be safely disposed of at the end of their lifetimes. To reduce this impact while testing, less intensive testing techniques have been employed to lower the need to replace specific parts on the device repeatedly, and to always follow the appropriate local regulations when disposing of such items. Since the team has sourced most parts off-the-shelf, however, assembly and testing has a limited impact on the device’s lifetime environmental impact.

B. Health and Safety
Lasers can cause eye damage if a laser is directed to an eye, but this mostly applies to high powered lasers that emit beams above 5mW, where the blink reflex is insufficient for protecting the user’s eye [6] [7]. Lower powered lasers, like the ones used in this project, in the range of 1mW to 5mW have a lower risk of causing eye damage if directed towards a person’s eye for a period of time. To further mitigate risks to health and safety, the duration of time for which the laser is on can be controlled; for example, only switching the laser on when directed towards the sky should minimize the risk of the laser shining into someone’s eye. However, doing so does not eliminate the risk of potential harm, so the system can be entirely powered down if some failure occurs.
C. Public Policy
Public policy surrounding the proper use of lasers is extremely relevant to this project. The Federal Aviation Association (FAA) reports laser incidents in which flying aircraft are a target of a laser, and these incidents can incur a fine and possible legal ramifications. Lasers may distract airplane pilots during takeoff, landing, and other emergency maneuvers or other low-altitude flight, and this is because even low-tomoderate class lasers on the order of milliwatts are still visible well into the sky, even 1 milliwatt lasers are visible 12 miles away in a dense city environment. Higher power lasers may also cause eye injury during flight, although as of February 2019, no documented cases of permanent eye injury in pilots have been recorded due to laser exposure according to the FAA [8]. To prevent possible legal ramifications, it is essential to be aware of the proper regulations and guidelines surrounding the use of lasers in outdoor settings. Because of this, a green laser with a power rating of less than 5 milliwatts was chosen for the project as per the guidelines [9].
D. Ethical Concerns
The major ethical in this project relate to public safety. Under the "FAA Modernization and Reform Act of 2012," the federal government made it a federal crime to direct a laser pointer at an aircraft [10]. As a direct result of this law, regulators keep track of the number of incidents involving laser pointers and aircraft. As responsible engineers, it is important to limit the possibility of the device enabling a user to break the law and being prosecuted for doing so. The risk of Mountain D.E.W. can address this issue by limiting the amount of time the laser points to the night sky.

Additionally, Mountain D.E.W. favors people who live in low light pollution areas. Rural areas, where there is less light pollution when compared to urban environments, have an easier time utilizing the device because the stars have greater contrast in the night sky. The users can look at the laser and immediately view the star the laser is pointing to, but in cities where light pollution occludes stars in the sky, users may not be able to identify the star which Mountain D.E.W. is pointing to.

The initial concept for Mountain D.E.W. utilized GPS to identify stars in the night sky. This could have posed a privacy concern to the users of the product. This concern could have been addressed by assuring users that location data is not stored or transmitted and is only used as part of celestial coordinate calculations for accurate and precise movement of the device.

E. Stakeholder Considerations
Considerations must be made regarding the concerns and interests of individuals involved in scientific research in astronomy, amateur astronomers or stargazers, and the wider astronomy educational community at large. The primary concern with the introduction of an inexpensive alternative to conventional laser-guided telescopes is the increased light pollution resulting from more widespread use: by nature of the device being a beam of artificial light fired into the night sky, should the device be utilized by numerous users centralized in a given region, the visibility of celestial objects is significantly diminished. With a focus on educational and amateur use, the device is designed to be an inexpensive alternative such that accessibility of basic astronomy education is greater, especially for underprivileged or disadvantaged demographics such as those in rural or inner-city areas. The advantage of this device is in its versatility in removing the barrier to access as a result of similar systems being conventionally attached to significantly more expensive telescopes. It is likely that this device will find its most significant usage as either a training aid for individual users or as a device for demonstrations for larger educational groups, such as scouting organizations or amateur stargazing groups. Considerations for the battery life of the system largely depend on the end-user: in conversation with the customer, it was decided that a range of 1-2hrs would suffice for the system, with either replaceable or rechargeable batteries used to prolong or restore power to the device. Similarly, in terms of accessibility, understanding that amateur users likely lack an in-depth understanding of the astronomical locations of celestial bodies, the inclusion of an LCD display is designed such that users will be able to select from a pre-determined list or database of known coordinates. Beyond technical design, if the device were to be placed on the market, a user’s manual would likely be necessary for accessibility to general-audience consumers.

IV. PHYSICAL CONSTRAINTS

A. Part Availability and Manufacturability
The materials required to construct this project were a STM32 micro-controller, a gimbal, a laser, a power supply, a screen, and a button and other input system. All components selected had common, off-the-shelf options available to be ordered online or in-person from major vendors, such as DigiKey, Mouser, or McMaster-Carr. If a certain part was not available, reasonable alternatives were purchased or even substituted from past Capstone projects and other self-acquired sources. Additionally, the department had already provided an STM32 Nucleo-64 Development Board and a class-3R laser to begin testing the product, which were incorporated into the final product as needed. All the parts and sensors were relatively inexpensive, and as such, it was initially expected that the project would be able to comfortably remain within the provided budget of $500. This ultimately was not the case (see section IX). Identifying inexpensive and off-the-shelf parts is key for decreasing the final cost of the device for customers, especially for a hypothetical production version, where every dollar saved may translate in thousands saved at scale.
V. EXTERNAL STANDARDS

The Mountain Directed Energy Wayfinder device is subject to several standards and regulations that govern limitations on both its operations and design. It is constrained by those standards set by the Institute of Electrical and Electronics Engineers (IEEE), International Electrotechnical Commission (IEC), Occupational Safety and Health Administration (OSHA), and American National Standards Institute (ANSI), among others. The following standards are most relevant to the design and operation of the device. Due to the abandonment of a GNSS-based approach, no such standards are considered. The standards relevant to this project are shown in table I. The use of a laser mandates compliance with relevant legal standards regarding laser operation and safety. Likewise, compliance must be met for general electrical safety. Additionally, testing procedures also must adhere to certain standards relevant to each technical area (i.e. motor operation, laser operation, electrical procedure, etc.). [11] [12] [13] [14]
[15] [16] [6] [17] [18] [19] [20] [21] [22] [23]

VI. INTELLECTUAL PROPERTY ISSUES

As part of this project, considerations of patentability and potential sources of intellectual property infringement are made. The project is comprised of several systems which may be reconfigured into several claims that would be considered.

A. Claimed Invention

The system apparatus may be described as follows:
1) A two-axis motorized gimbal comprising
a motor for the purpose of movement along an elevational axis;
a motor for the purpose of movement along an azimuthal axis;
a counterweight for the azimuthal axis motor; a fixture attached to the rotating axle of the elevational motor for the purpose of attachment to a light-emitting device.
an armature onto which the elevational motor and its counterweight are mounted, and is itself mounted onto the rotating axle of the azimuthal motor;
a housing onto which the azimuthal motor, a power supply circuitry board, and a display may be mounted, and itself may be situated onto a mount.
2) The apparatus of claim 1, wherein the light-emitting device is a laser diode.
3) The apparatus of claim 2, wherein the laser diode emits green light.
4) The apparatus of claim 1, wherein the motors are bipolar stepper motors.
5) The apparatus of claim 1, wherein the housing is configured to mount onto a tripod.
6) The apparatus of claim 5, wherein the display is a liquidcrystal display.

TABLE I
STANDARDS AND REGULATIONS
Standard or Regulation | Relevant Area
OSHA STD 01-05-001: Guidelines for Laser Safety and Hazard Assessment II-1 A. Basic Laser Operation III-2 C. Ocular Effects of Laser Radiation III-9 H. Maximum Permissible Exposure Limits V-1 B. Laser Hazard Classes | Laser safety
OSHA 1910 Subpart I: Occupational Safety and Health Standards: Personal Protective Equipment 1910.132, General requirements 1910.133, Eye and face protection | General guidelines
528-2019 - IEEE Standard for Inertial Sensor Terminology | Gimbal testing
647-1995 - IEEE Standard Specification Format Guide and Test Procedure for Single-Axis Laser Gyros | System testing
813-1988 - IEEE Specification Format Guide and Test Procedure for Two-Degree-of-Freedom Dynamically Tuned Gyros | Gimbal testing
IEC 60825: Safety of laser products IEC 60825-1: Part 1: Equipment classification and requirements | Laser safety
IEC 60950-1: Informational technology equipment - Safety - Part 1: General requirements | Electrical equipment
IEC 61747: Liquid crystal display devices - Part 4-1: Matrix colour LCD modules - Essential ratings and characteristics | LCD operation
RoHS 3 Directive 2015/863/EU: Restriction on the use of certain hazardous Substances | Electrical equipment
21 CFR Part 1040: Performance standards for light-emitting products 1040.10 Laser products 1040.11 Specific purpose laser products | Laser safety
ANSI Z136 Series: Guidelines for Implementing a Safe Laser Program Z136.1 - Safe Use of Lasers Z136.5 - Safe Use of Lasers in Educational Institutions Z136.6 - Safe Use of Lasers Outdoors | Laser safety
NEMA SEM S1-2018: Small Electric Motors | Motor safety
ANSI/NEMA MG 1-2021: Motors and Generators | Motor safety
7) A method for driving the motors, through open-loop
control, of the apparatus of claim 1, to direct the fixture
to a pre-determined celestial coordinate.
8) The method of claim 7, wherein the celestial coordinate is determined through a calculation of Greenwich-mean sidereal time, incorporating
the latitude-longitude; and
the right-ascension-declination of a given celestial body.
9) An analog electronic circuit configured to step down a DC voltage input, comprising of
a subcircuit configured to supply power to a DC motor;
a subcircuit configured to supply power to a microcontroller; and
a subcircuit configured to supply power to a light-emitting device.
10) The apparatus of claim 9, wherein the subcircuit configured to supply power to a DC motor supplies 12 volts.
11) The apparatus of claim 10, wherein the subcircuit configured to supply power to a DC motor is configured to supply 12 volts to two bipolar stepper motors.
12) The apparatus of claim 9, wherein the subcircuit configured to supply power to a microcontroller supplies 5 volts.
13) The apparatus of claim 9, wherein the subcircuit configured to supply power to a light-emitting device supplies 3.3 volts.
14) The apparatus of claim 13, wherein the light-emitting device is a green laser diode.
The patentability of the apparatus and its subsystems are evaluated as follows. The robustness of the claims stated here are not comprehensive, and should be considered preliminary.
B. 35 U.S.C 101
The subject matter eligibility of the apparatus and its systems are not under question under 35 U.S.C 101, in regards to inventions patentable. The system and its subsystems are acceptable as a "process, machine, manufacture, or composition of matter", and do not fall under the categories of "abstract ideas, laws of nature and natural phenomena (including products of nature)". Additionally, the invention meets the standard of being "useful" or having "a utility that is specific, substantial and credible", as detailed in regards to the functionality and operation of the invention in section VII. [26]. Under the ruling of Alice Corporation Pty. Ltd. v. CLS Bank International et al., 573 U.S. 208 (2014), any software subject matter must also be applicable to the implementation of unique non-software. subject to the same criteria as an apparatus being considered for eligibility. [27] The embedded software implemented as part of this project controls the precision movement of bipolar stepper motors: this action is not patentable under 35 U.S.C. 103, as detailed in section VI-D. However, the calculation of precise steps to move in order to locate specific star coordinates is a non-obvious solution that may be patentable, as detailed in section VI-E2.
C. 35 U.S.C. 102
Under 35 U.S.C. 102(a), post-America Invents Act (AIA), an invention may be eligible for patentability unless the "claimed invention was patented, described in a printed publication, or in public use, on sale, or otherwise available to the public before the effective filing date of the claimed invention". [28] In a sense, 35 U.S.C. 102 considers "anticipation" of a claimed invention based on previouslypublishes or otherwise disclosed prior art.

Claims 1-2 would likely be rejected as being anticipated by Blackburn ’458 (US 8982458 B2). [29] Blackburn teaches in independent claim 1 a "beam director, comprising: a beam director elevation motor elevation motor that rotates the beam director about an elevation axis; a beam director azimuth motor that rotates the beam director about an azimuth axis, the azimuth axis intersecting and being substantially perpendicular to the elevation axis". This is directly comparable to the two-motor gimballed system with a laser as specified in the assembly of the claimed invention.

Claims 9, 13, and 14 would likely be rejected as being anticipated by Khalili ’404 (US 2005/0185404 A1). [30] Khalili teaches in independent claim 2 a "voltage conversion circuit to provide power to the laser diode with fixed intensity of light...wherein a highly efficient DC to DC converter circuit made from discrete components or integrated circuits...mounted on a PCB or similar assembly". Therefore, the power circuitry included as part of the assembly of the claimed invention would be unpatentable, due to anticipation by Khalili.

D. 35 U.S.C. 103

As previously mentioned, the system is not disclosed by any one specific element of prior art. However, according to 35 U.S.C. 103, post-AIA, an invention may not receive a patent if "the differences between the subject matter sought to be patented and the prior art are such that the subject matter as a whole would have been obvious at the time the invention was made to a person having ordinary skill in the art to which said subject matter pertains." [31] The criterion therefore indicates a greater flexibility: the question is asked of if it would be obvious for a person having ordinary skill in the art – in this case, assumed to be a career electrical engineer who does not have astronomical experience – to examine two pieces of prior art, and combine them such that the claimed invention is not patentable.

Claim 5 would be rejected as being unpatentable over Blackburn ’458, in view of Davidson ’881 (US 4196881) [32]. Davidson teaches in independent claim 1 "a tripod, comprising mounting means for removable mounting of a camera or the like, three legs having independently articulating connection", which succinctly defines the structure of the tripod structure that would likely be used for the mount for the housing mentioned.
Claim 7 would be rejected as being unpatentable over Blackburn ’458, in view of Chandhoke ’310 (US 2009/0051310 A1) [33]. As previously stated, Blackburn materially teaches claim 1. Chandhoke teaches in independent claim 1 "a method for controlling a stepper motor...generating a new position value to drive the stepper motor; providing an output position value to the stepper motor to drive the stepper motor". While Chandhoke specifies a closed-loop method of motor control, the obviousness criterion is also supported in terms of common knowledge in the art: "the rationale may be expressly or impliedly contained in the prior art or it may be reasoned from knowledge generally available to one of ordinary skill in the art, established scientific principles, or legal precedent established by prior case law". [34] Based on this additional criteria, claim 7 would further be rejected: it would be obvious for a person having ordinary skill in the art to control stepper motors using an open-loop system, due to it being common knowledge. As such, it would be obvious to a person having ordinary skill in the art to combine the apparatus of Blackburn with the motor control method of Chandhoke, such that the motors in the apparatus of Blackburn may be driven with the method of Chandhoke.

The rationale found in Section 2144 of the Manual for Patent Examining Procedure [34] would likely also be used to reject claims 3, 4, and 10.

E. Allowable Subject Matter
Due to the rejection of what would be independent claims 1, 7, and 9 it is likely that claims 6, 8, 11, and 12, as dependent claims, would be objected to as being dependent upon a rejected base claim; would be allowable if rewritten in independent form including all of the limitations of the base claim and any intervening claims.
1) Hardware Subject Matter: As to claim 6, at time of writing, no such gimballed motor system incorporates an LCD display with associated display control was found. If specified as such, it is possible that the overall apparatus, incorporating the unique addition of the LCD display, may potentially be patentable.

As to claims 11 and 12, the powering of a microcontroller is not disclosed by a known prior art as of time of writing.
2) Software Subject Matter: As to claim 8, the most likely allowable subject matter present as part of the invention is the embedded software program for the control of the motor systems. As previously mentioned in section VI-D, the act of stepping motors itself may be considered obvious to a person having ordinary skill in the art. As briefly introduced in section VI-B, the calculation of the precise steps to move in order to locate specific star coordinates is a non-obvious solution given a person having ordinary skill in the art, assumed to have the layperson’s knowledge of astronomy. The complexity of the calculation is found in its incorporation of an understanding of three factors:
1) Greenwich-mean sidereal time, as derived from the Julian date, as derived from the Gregorian date and current clock time.
2) Latitudinal and longitudinal coordinate systems, such that they may be applied to calculate the azimuthal and elevational position of a given star.
3) Right-ascension and declination celestial coordinates, such that they may also be applied to calculate the azimuthal and elevational position of a given star.
As such, with express application towards a material, unique result, the embedded software applicable to the movement of the motors, for the purpose of directing the laser towards a specific star coordinate, may be considered potentially allowable subject matter.

F. Software License Agreements
The software libraries used for this project, including the TouchGFX library, is licensed under the STMicroelectronics SLA0048 software license agreement. [35] The PEPCISco design team acknowledges and accepts, in using STM-sourced libraries, the software package license agreement, and has maintained compliance with the details of the agreement, in using the relevant provided software for strictly educational purposes as opposed to commercial applications.

VII. PROJECT DESCRIPTION

A. Objectives
Mountain D.E.W. (Directed Energy Wayfinder) is an educational tool designed to assist novice astronomers and stargazers in identifying and seeking stars in the night sky. To accomplish this, the device was initially designed to incorporate a GNSS module that receives spatial coordinates and time data and then references an on-board database of existing celestial bodies to orient the device. This aspect has since been abandoned. Users are then able to select a desired star for viewing, upon which the device parses through the sky, moving a laser, mounted to a two-axis gimbal, to point at the star in question. The device incorporates the STM32 Nucleo-G071RB microcontroller, along with a X-NUCLEO-GFX01M2 LCD expansion board, as the primary processing unit, due to the robustness and flexibility of the microcontroller [36]. The STM32 Nucleo is responsible for the operation of laser power, input processing, user interface display, and the pulse-width modulation signals that drive the stepper motors. The microcontroller and associated circuitry is located underneath the main gimbal platform. A diagram of both power and data flow is shown in figure 1.

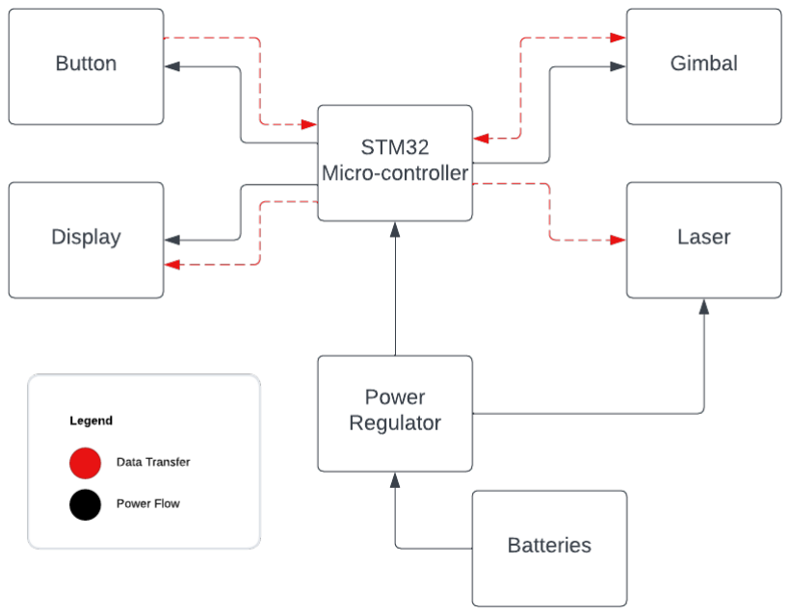
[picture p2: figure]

Fig. 1. Block Diagram - Power Flow, Data Transfer

B. Functionality
The first step is for the user to place the device in an area where the night sky is present. Stars should be visible to the naked eye in this area. When the device is powered, the user will input their current latitude and longitude using the joystick button located on the LCD display. Next, the user will enter the current date and time. After that, the user will confirm their selection and then use the joystick to maneuver the laser to point at Polaris, the north star. Then, the user will select a given star from a list on the LCD, and the device will determine the star’s azimuth and elevation with respect to the user. Mountain D.E.W. seeks out stars by parsing GPS data to find the device’s location and time and then directs the laser to the star via controlling the stepper motor drivers that move the gimbal. The user will be able to select a new star, then the process is repeated as many times as the user wants it to or until the machine is powered off.

To correctly align the system and point the laser at the correct star, the device will need to be able to interpret the celestial coordinate system. There are five different systems to choose from, each with a different fundamental plane that they base the system off. One option that may be used is the equatorial system [37]. This system is used by many professional and amateur astronomers and uses the Earth’s center as its relative origin. Coordinates are based off the locations of stars relative to the Earth’s equator. This coordinate system uses two values: declination and right ascension. Declination is the measure of where an object is between the north celestial pole and the south celestial pole and can have a value from -90° to 90°. Right ascension (RA) is the measure of where an object is along the equator and is measured relative to the Vernal Equinox Point. RA is dependent on time since the Earth spins, and thus sidereal time to find the RA must also be calculated [38]. Sidereal time can easily be calculated on-board the device, by using a GPS module and by inputting time manually. To perform the initial orientation of the device, the laser can be pointed at the north star, Polaris, which is located at the north celestial pole. Next, the combination of GPS data and time will be used to calculate the initial RA. After this, the device will know exactly where it is and where it is pointing, allowing it to calculate how to point at any other start in the night sky.

C. Technical Considerations
Mountain D.E.W. is comprised of six design blocks, incorporating (1) a laser mounted onto (2) a two-axis gimbal, controlled by (3) an STM32 G071RB microcontroller, powered by (4) a standalone power supply, with (5) a GPS chip for calibration and geolocation, and (6) a user interface comprised of a button and LCD display. The technical feasibility of such a design has been proven by amateur inventors utilizing an Arduino-based system [39]. Scaled down to what is technically feasible within the scope of a 2.5-month project, the versatility of the STM32 microcontroller [40] and the extensive documentation available for applications of the STM32 [41] allows for a more-streamlined application of the microcontroller to the purposes of this project. Health and safety concerns restrict the operation of a green laser to 5 milliwatt, which has been demonstrated to be sufficient for amateur astronomical usage [42]. In terms of the operation of the gimbal, use of a two-axis gimbal requires considerations of pitch (rotation relative to a transverse axis) and yaw (rotation relative to a vertical axis), as shown in figure 2.

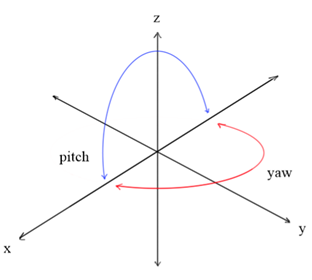
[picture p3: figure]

Fig. 2. Pitch and Yaw Definition

For the purposes of the operation of Mountain D.E.W., the device requires, for its two degrees of freedom, the ability to move 360[Equation] in yaw, and 90[Equation] in pitch, for both vertical operation and near-horizontal operation. Considerations for stability of motion for when the device is oriented are available and will be made a primary priority, such that smooth movement and orientation of the gimbal-mounted laser are made possible [43]. It is expected that the device will be able to operate independent of a wall power supply: this restricts the operation of the device to battery operation. A 12V lead-acid battery was chosen due to the large capacity and sufficient voltage output [44].

To supply power to the entire system, a series of buck regulators was implemented on the PCBs. As the system was originally designed to be supplied by 18V from two 9V batteries, the power is initially fed into an AP63300 buck regulator which steps the voltage down from 18V to 12V [49]. Using the equations found on the regulator’s datasheet, resistors, capacitors, and inductors that would output 12V and supply the necessary current were selected. The 12V output from the AP63300 is then used to power the STM32 as well as the stepper motors via the motor drivers. It also goes into an AP62150 buck regulator that steps the 12V down to 5V [50]. Again, the AP62150 datasheet was consulted to select the support circuit elements. The 5V from the output of the AP62150 is used as an alternate power source for the STM32 and power for the laser. A final buck regulator converts the 5V to 3.3V. An AP61100 buck regulator was chosen and its datasheet was used to select the required component values [51]. The 3.3V output from the buck regulator was used to provide power to the original motor drivers before another motor driver was found [52]. It was also used to provide an input to a 3.3V low-voltage dropout (LDO) regulator since the Adafruit GNSS module required a smooth voltage supply which a buck regulator cannot provide [53].

The STM32 has a wide variety of modules and expansion boards that allow for easy integration of the different subsystems this project requires. Initially, the GY-NEO6MV2 GPS module was chosen, however, the required pins it uses for data transmission conflicted with pins that were used by the LCD display module. This forced the team to use the

Adafruit PA1616S GPS breakout board which was able to communicate using the UART serial data communication protocol on different STM32 pins. The LCD module chosen, the X-NUCLEO-GFX01M2 interfaces directly with the STM32 microcontroller. The LCD module also features a 64-Mbit NOR Flash memory which stores the images and typography that is displayed on the LCD. Both the LCD and NOR Flash communicate with the STM32 using the SPI (Serial Peripheral Interface) communication protocol. The LCD module also features a joystick which can be pressed in the center, up, down, left, and right directions. This joystick and the board’s on-board user button is the primary method that users will use to interact with the system and is used to set the latitude and longitude, move the laser during initial orientation, and select which star to point at. Another feature of the LCD module is its usage of the TouchGFX graphical user interface (GUI) framework. TouchGFX was used to generate all of the screen images that the user interacts with on the LCD.

To calculate the azimuth and elevation of a celestial body with respect to some observer on the Earth’s surface, the user’s latitude and longitude, the body’s right ascension and declination, and the Greenwich mean sidereal time (GMST) must be known. Sidereal time is a measure of how much the Earth has rotated with respect to distant celestial objects, with sidereal time relative to the Prime Meridian in Greenwich as the standard used by astronomers for converting right ascension and declination to pitch and yaw code. [55] GMST can be calculated from the current time of day and the user’s timezone, which are first converted to the Julian Date using the following equations: [56]
A = INT
M − 14

12

B = 1461 (Y + 4800 + A)
C = 367 (M − 2 − 12A)
E = INT
Y + 4900 + A

100

(1)

JDN = INT
B
4

+ INT
C

12

−INT
3E
4
+ D −32075

(2)
The Julian date and time can be used to find the Greenwich mean sidereal time using the following equation: [57]

where the hour angle can be found using the following formula: [58]

The Greenwich mean sidereal time is used instead of the Greenwich apparent sidereal time to reduce the complexity of the calculation, as an error of 1 second (or 0.0003 degrees) is not detectable to the naked eye. [55] The GMST, observer latitude and longitude, and right ascension and declination can then be used to find the azimuth and elevation of a given celestial body using the following formulas to calculate its hour angle (or position relative to the Prime Meridian), and then finding the azimuth elevation coordinates: [59]

H = GMST + lon − RA
az = arctan 2 (sin(H), cos(H) sin(lat) − tan(Dec) cos(lat)) alt = arcsin (sin(lat) sin(Dec) + cos(lat) cos(Dec) cos(H))
D. Design Challenges

The major challenge that this project faced was the determination of the initial orientation of the device and how to use available databases of celestial objects to point the laser at the correct star or planet. Multiple techniques to determine the initial orientation of the device have been considered during the preliminary planning phase. For the purposes of this proposal, a decision was made between two orientation techniques: the use of a camera to map the visible stars and determine the initial orientation, or pointing the laser at the north star, Polaris, and using a GPS module. Using a camera to orient the device poses many technical challenges. First is ensuring there is enough resolution in the camera to be able to identify individual stars in the sky. If the camera quality is poor, the image will be too blurry to determine what stars the device is looking at. Second is making sure that the STM32 Nucleo board and its accessories have enough processing power to quickly perform the calculations necessary to process the image, which depend on the amount of data and the algorithm chosen for the task. Orienting the system using Polaris also poses challenges since it will need to be manually pointed at the star, introducing a degree of error from the manual inputs. Additionally, this limits the functionality of the system to the northern hemisphere since Polaris is only visible from there. The device could be made to orient to Sigma Octantis, the pole star of the southern hemisphere, but further research will have to be done [54]. On the other hand, using a GPS module would only require that the device’s initial orientation will be relatively level with respect to the ground, as the latitude, longitude, and type of day can be parsed from GPS data at a much lower power and computational cost than the orientation based on image processing alone. While this does introduce the challenge of initial orientation, this may also be addressed through manual calibration via the user or the use of additional sensors or header boards, such as an inclinometer for the laser’s initial position.

Another major challenge that was faced was choosing the best method to power the system. Initially, two 9V batteries in series were chosen to power the system. This would provide 18V which would then be stepped down to 11.1V, then 5V, and ultimately 3.3V. After switching gimbal systems, the

11.1V level had to be re-designed to output 12V instead. Upon testing, it was discovered that the 18V to 12V switching regulator did not function on any of the PCBs that had been soldered and as such were forced to abandon it. This meant that the power source had to be switched from the two 9V batteries to a single 12V lead-acid battery which would then be connected directly to the input of the 12V to 5V regulator. This battery is very bulky and heavy which means it is hard to transport.

From the standpoint of human factors engineering, it is necessary to ensure that the system is both safe and easy to use, which poses a challenge if the device primarily initialized and used in dark environments. From a safety standpoint, the laser specified is low power at less than 5mW: common-sense precautions are intended to be designed into the device, such as only allowing the laser to turn on when the device has finished gimbaling to decrease the chance that it may cause injury to user vision. The laser may instead be configured to only circle around the area of interest a certain number of times instead of pointing directly at the area of interest. Proceeding with this methodology, the smoother the system runs with minimal user input, the less the user will need to mess with the device and risk having the laser point into their eye. Having LEDs or some other method of signaling to the user that the board is powering on, calibrating, or adjusting itself, may help increase the amount of feedback that the user gets to prevent them from spending too much time around the device. These features will be iterated for additions and improvements, for the purpose of improving safety and ease of use.

E. Test Plan

Once each component of Mountain D.E.W. has been acquired, the PCBs were assembled and soldered. Next, the power supply circuitry on the PCB was tested to ensure that each electrical component was getting the correct voltage and power. Then, each piece of hardware was tested by sending the corresponding control signals for each basic function, or state of the device, and verified that the correct output was measured and/or observed for each set of inputs. For the laser, for example, a check was made for the laser to turn on when it receives the right set of control signals. The display’s output would verify that the data sent to the board is visible and correctly oriented for the user. For the input system, this test also required verification that the data being fed in meets specifications for each subsystem. Next, the software that controls the gimbal was tested to verify that it points where it is instructed to within the testing program. Lastly, the gimbals were verified to have the capability to correctly move the laser, or a dummy payload representing the laser, from one star to another once the system is correctly calibrated.

After testing each component manually, the system was assembled in stages with basic tests for connectivity occurring when each module was attached. The microcontroller and laser were the first to be assembled, such that their joint functionality may be verified for each relevant state, proceeded by integration of the gimbal, displays, and input system until complete integration was achieved and tested.

F. Resources & Equipment
To complete this project, access to soldering equipment, a 3D printer, multimeter, and other standard electrical test equipment was required. The soldering equipment was needed to solder electrical components like resistors and voltage converters as well as make any other connections to the laser and gimbaling system that were required. The 3D printer was needed to manufacture the housing for the device. The PCB and gimbaling system need a structure to support them, and designing a casing using software like Autodesk Fusion 360 provided the most freedom. To make sure the PCB is functioning properly, electrical test equipment like multimeters, oscilloscopes, and a power supply were necessary so that the power supplied to the system could be controlled, and any possible damage that would otherwise result could be prevented.
G. Software
The software tools that used for this project include tools that were used to develop both the hardware components, software components, and case design. The tool used for board development was KiCad. It was used for the initial circuit schematic capture and for PCB layout. Software tools used for this project include the STM32 CubeIDE, STM32CubeMX, and TouchGFX for embedded system coding and VSCode for other coding related activities. The group used a Git repository hosted on Github for version control for development of the device’s code base. Lastly, the casing for the project was designed in Autodesk Fusion 360, which is computer aided design (CAD) software.

VIII. TIMELINE

From a high-level perspective, the Gantt chart from the proposal sufficiently estimated the amount of time that was needed to complete the initial project proposal, initial design, and the first rounds of parts orders. Where the Gantt chart failed was usually in two places: 1) no time was allotted on the original Gantt chart for the completion of the Poster Session material and Midterm Design Review, as well as the Final Video, and 2) insufficient time was budgeted for not only the assembly of each subsystem and their integration, but also the time needed to properly improve and iterate upon each subsystem. Additionally, the original Gantt Chart does not reflect the additional time the group built into the final report due to delays in shipping for various products, such as the original planned gimbal from CopterLabs, which increased the time needed to assemble each subsystem and integrate it into the whole device. For group assignments like the Project Proposal, the initial approach was to divvy up the work by subsection, and then having each member read over the whole product at the end. This approach quickly broke down when the Project Description section, given its length and subject material, needed the input of multiple members for completion. Thus, Errick was switched in to help with the Project Description in addition to the External Considerations, while Jeffrey was assigned to take over the Test Plan. Additionally, due to a miscommunication, Anthony also completed a large portion of the External Considerations section, so Jeffrey also helped take over the budget outline. Given all the role-swapping with the Project Proposal, when deciding roles for the next report assignments, the team felt that a less rigid division of responsibilities would give each member more flexibility in giving input to others’ sections. Doing so would also clutter the Gantt Chart less, since each member still had to address their responsibilities for designs and ordering during that same period of time. This approach was successful enough that the team chose to go with the same approach for creating the Final Video and Report, where material created for past reports could be recycled and updated with input from other team members as necessary. To save space on the figure above, this more flexible arrangement has simply been noted as a full ‘Team’ responsibility on the final Gantt Chart, keeping in mind that the responsibilities for each section carry over from the Project Proposal but with the need for each member to collaborate with each other to complete the entire deliverable. Shifting to more technical logistics, the initial design and orders section of the Gantt Chart had to be modified as the group made decisions and changes about the exact materials needed for the project. This included: 1) splitting the line for laser acquisition into laser source and laser mount, 2) adding GNSS and LCD expansion board acquisition tasks, 3) condensing the gimbal chassis, motor, and sensor acquisition tasks into a single task to reflect the initial plan to use an off-shelf gimbal and motor assembly. The programming tasks associated with this period were also augmented with a laser control FSM task, since the team felt that a clearer idea of the device’s UI was necessary for designing the algorithms for adjusting and calibrating the motors. Finally, the gimbal and the first iteration of the PCB had to be extended an additional week due to delays in shipping, with the calibration code design also extended due to uncertainty regarding the gimbal.

With regards to the initial stage of assembly and testing, the initial Gantt chart failed to take into account what would happen if the design for a subsystem failed subsystem testing and required further iterations before it could even begin system integration. Case in point: when the Copter Labs chassis arrived, it was quickly realized that the subsystem did not meet the specifications given by the client. Thus, the Gantt chart had to be updated to reflect that assembly and testing for the laser, backup gimbal motors, and the LCD was completed, but also to show that chassis assembly required more time. Extra lines for software testing with the FSM, GNSS, and LCD were also added to this part of the project. As the project progressed, the team realized that certain components could not be used in conjunction with the LCD due to overlapping digital pin requirements. This affected the order in which components could be integrated into the entire system, as certain parts needed to be re-designed and re-ordered based on what pins the team could use from

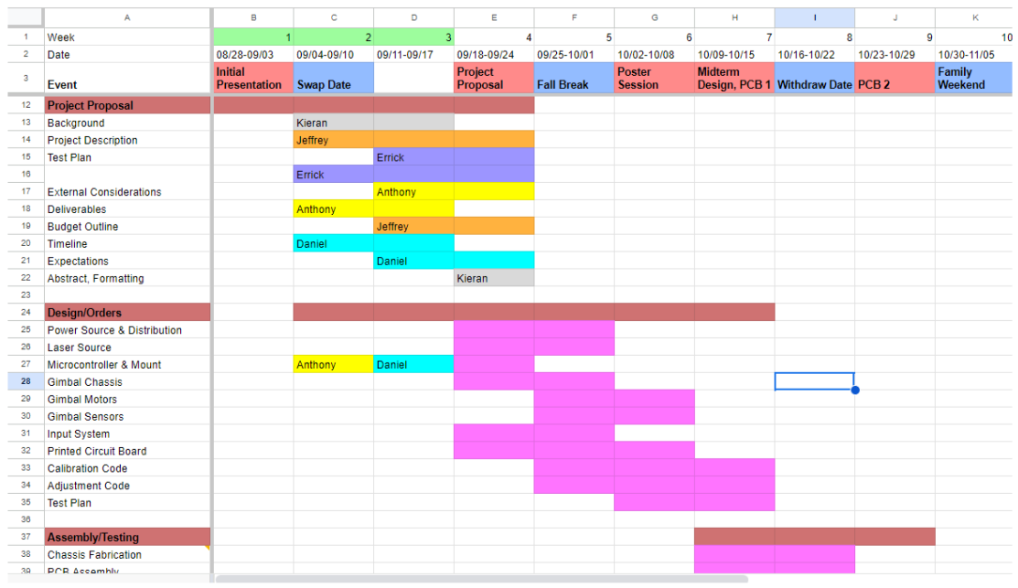
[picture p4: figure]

Fig. 3. Initial timeline for project proposal, design, and component orders.

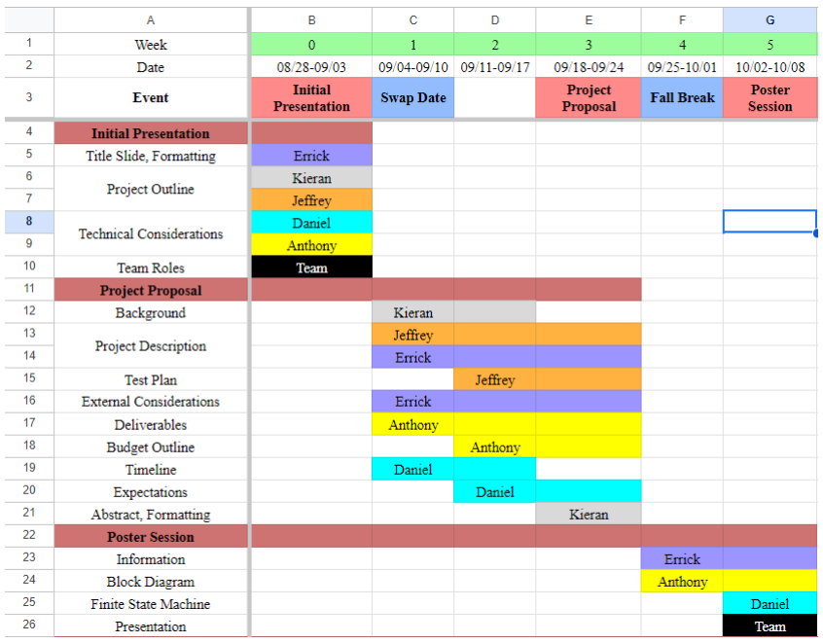
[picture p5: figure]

Fig. 4. Final timeline for initial presentation, project proposal, poster session.

the STM board. Thus, the order of integration became: LCD, GNSS, Power PCB, Gimbal, Laser, and then DC Power Supply. The GNSS board had to be re-ordered with a different model from Adafruit, while the PCB had to be split into STM and Power PCBs to better fit the planned casing.

The motorized gimbal had to also be completely reworked into an 3D printer armature design. While every component was eventually integrated into the system powered by a DC power supply for field testing at the residence of Mr. Dudley White, generously offered, this still resulted in three weeks of

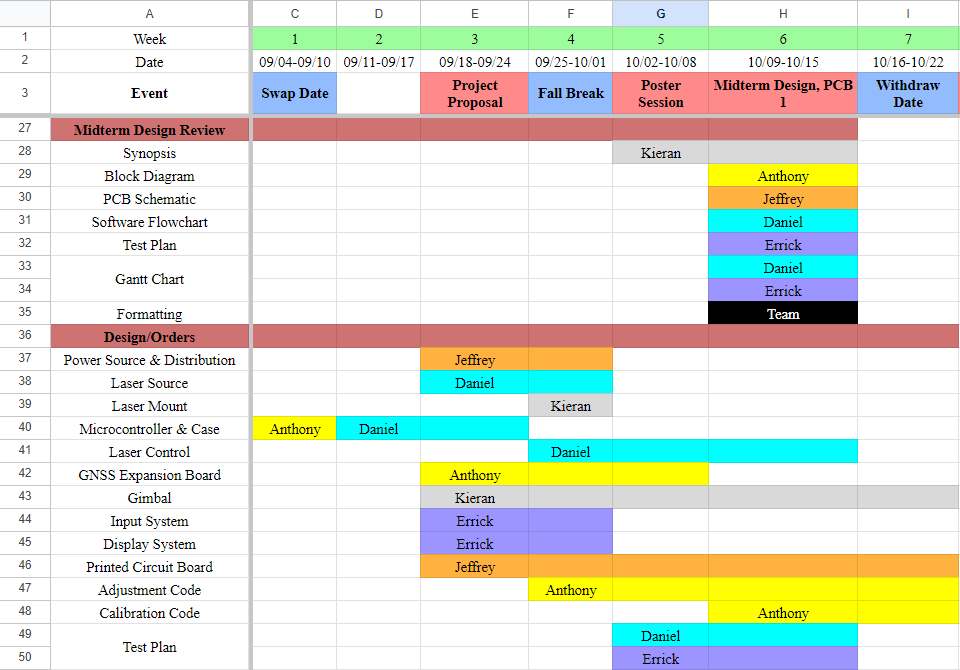
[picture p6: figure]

Fig. 5. Final timeline for midterm design review, design, and component orders.

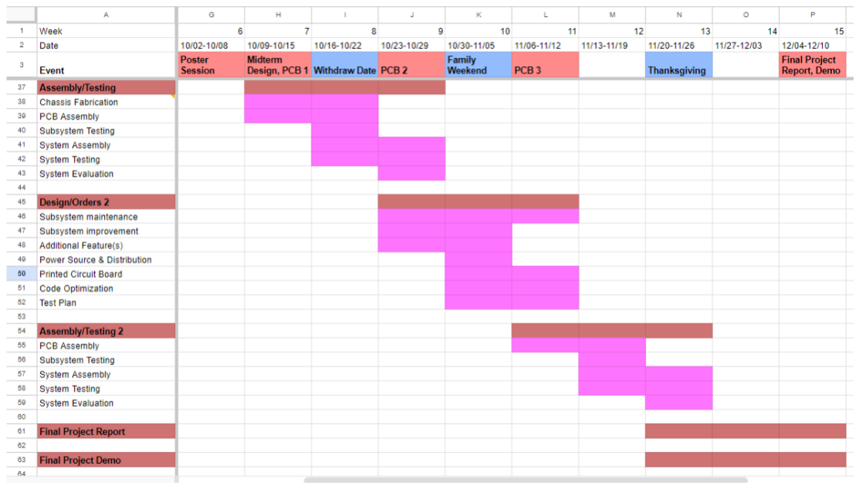
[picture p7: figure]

Fig. 6. Initial timeline for assembly, testing, second design iteration, final report, and demo.

delay from the original Gantt Chart. Thus, the team pivoted
towards improving certain aspects of the project from the
rubric to increase score, instead of completing another full design cycle on the device.

For the last three weeks, instead of going through a second design cycle, the team split into groups to focus on getting the GNSS board integrated into the system, improving the

Power Supply PCB, and 3D printing a tripod mount for the entire system. While the latter two objectives were achieved by the end of November, the GNSS board could not be integrated due to difficulties with the TouchGFX library. Thus, additional screens had to be added for the user to manually input their latitude, longitude, and time of day.

All in all, while the group was unable to complete its orig-

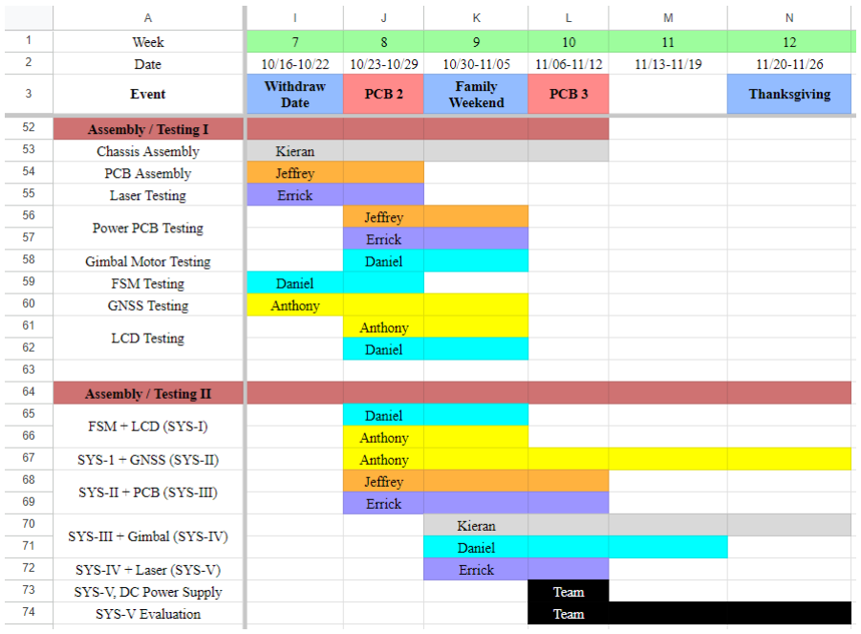
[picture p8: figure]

Fig. 7. Final timeline for assembly, subsystem testing, and integration.

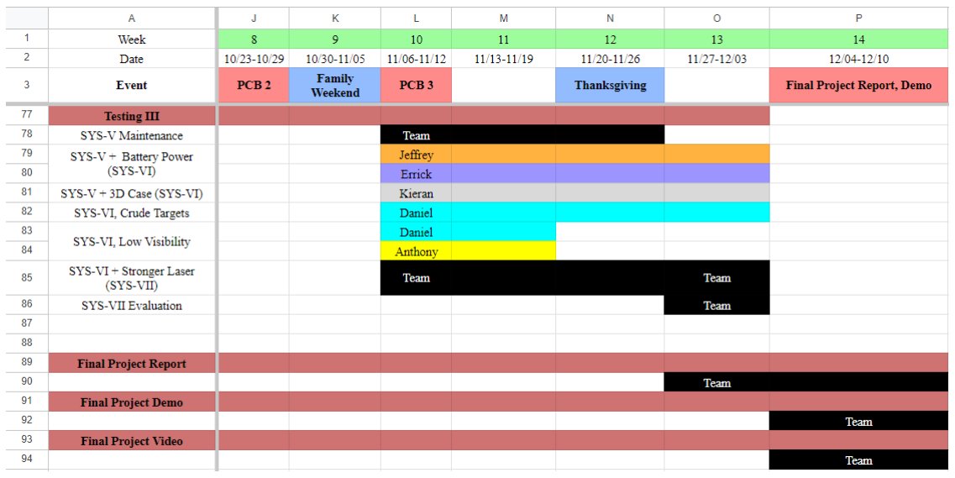
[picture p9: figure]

Fig. 8. Final timeline for system testing, field testing, and demo.

inal intended schedule of design with two cycles of assembly and testing, the team was still able to achieve a functional device prototype even when presented with delays in shipping, issues with pin configuration, and challenges with printed circuit board design. While certain aspects of scheduling and the chart could be improved in the future to better reflect the parallel nature of subsystem development and iterative design, this Gantt chart served its purpose well in guiding the team in its efforts creating its final demo, report, and video.

IX. COSTS

The cost of the project development can be seen in Appendix-A and Appendix-B. A full outline of the cost of both a single unit and mass production of 10,000 units can be seen in Table II.

TABLE II
COSTS SUMMARIZED
Subsystem | 1 unit ($) | 10000 units ($)
PBB | 1.96 | 0.75
Components | 29.47 | 12.04
STM | 11.21 | 10.21
LCD | 35 | 35
Stepper Motors | 28 | 28
Laser | 105 | 105
Mechanical Components | 8.33 | 0.50
Motor Drivers | 9.30 | 9.30
Tripod | 15 | 15
Battery | 20 | Not Included
Total | 263.27 | 215.80
A. Single Unit
The total cost of the device of $263.27 as can be broken down into 6 major components: Custom Electronics, Embedded Electronics, the Motors, the laser, the battery, and Mechanical Setup. The custom electronics consists of a Power PCB with components soldered onto it and a breakout PCB for the embedded electronics. The PCBs cost $9.80 for 5 boards so $1.96 per board and the components that were soldered onto the PCBs cost a total of $29.47 per board, an itemized version of which can be seen in the appendix. The embedded electronics consists of an Nucleo G0B1RE with the LCD header board, the X-NUCLEO-GFX01M2. This cost $11.21 for the STM32 and $35.00 for the LCD Header. Two motors, 324 Adafruit Industries LLC Stepper Motors, which cost $14 each for a total of $28 were purchased. The laser, the VLM-520-52 LPB, cost $105. To power the setup, a lead acid battery for $20 was used. Finally the mechanical setup consists of custom 3D printed parts in PETG plastic. Each roll of 1Kg of plastic costs $24.99 and each mount is approximately 1/3 of a kilogram of plastic of which approximately 0.3Kg is the tripod and electrons mount and the mount is approximately 0.05Kg. This least to a total 3D printed cost of $8.33. The tripod, Targus TG-5060TR, costs approximately $15. The motor drivers in the final project, the SparkFun Quadstepper Motor Driver Board, is no longer made or sold so Allegro A4988 were used to estimate the cost. These drivers are $4.65 a piece and 2 drivers are needed for a total of $9.30.
B. Mass Production
If this device were purchased on a large scale of, for example, 10,000 units the cost of each device would fall to $215.80 battery not included. The laser, motors, motor divers, tripod, and the embedded electronics do not decrease in price with scale from any current suppliers. However, with the STM it may be possible to create a board with the micro controller and power electronics directly connected potentially saving approximately $1. The components that were soldered on the board do greatly scale with unit costs. The chips and larger components such as MOSFETs and jumper pins reduce in price by approximately 60%. Smaller component such as capacitors are approximately 80% lower in cost. This leads to an overall drop in cost for the electronic components to about $12.04 per unit. The PCBs drop to $0.75 on an order of 10,000. Additionally, the 3D printed components could be converted to injection molded which would likely reduce unit costs to approximately $0.50. The battery would not be included in a production outfitting.
X. FINAL RESULTS

The rubric by which the project is scored is detailed in Table III. The performance metrics shown dictate how the project demonstrates a sufficient degree of operation.

A. Power

Score: 2
- Stepper Motor Control Board: 1A @12V (12W)
- STM32 + LCD: 300mA @12V with 92% efficiency (3.9W)
- Laser: 380mA @ 5V with 92% efficiency (2.1W)
- Battery capacity: 12V 7Ah (84Wh)
- Maximum time on: 4.5h
Even at maximum output, the device can operator for more than hour on a single charge.
B. Laser

Score: 2
Laser tick-based events implemented circling implemented to a limited extent, however, after field testing, it was realized that circling the laser increased the risk of hitting nearby aircraft and decided to shift back to just single pointing.
C. PCB

Score: 2
A single PCB design is split into two to allow for more compact, modular design. All components are successfully soldered on with a fabricated case/mount.
D. Gimbal

Score: 2
The gimbal is fully assembled with laser. All components are well mounted and set on a tripod raised above the ground which allows user to stand instead of having to crouch down avoids dirt and other material on the ground that could affect device operation heat sinks placed also help regulate the gimbal’s internal temperature.
E. User Interface

Score: 2
The system features 23 stars. More stars can be added so long as the star’s RA and Declination coordinates are known. The system stores star ID on the microcontroller, and has options for manually inputting the time of day, latitude, and longitude and displaying the corresponding azimuth and elevation for each star.
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

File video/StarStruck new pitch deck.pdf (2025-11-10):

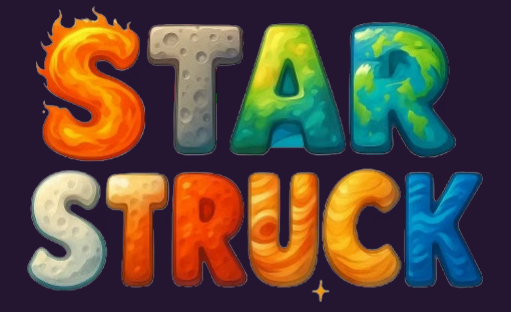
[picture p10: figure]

### Making Space Exploration Accessible & Engaging

Astronomy = Science

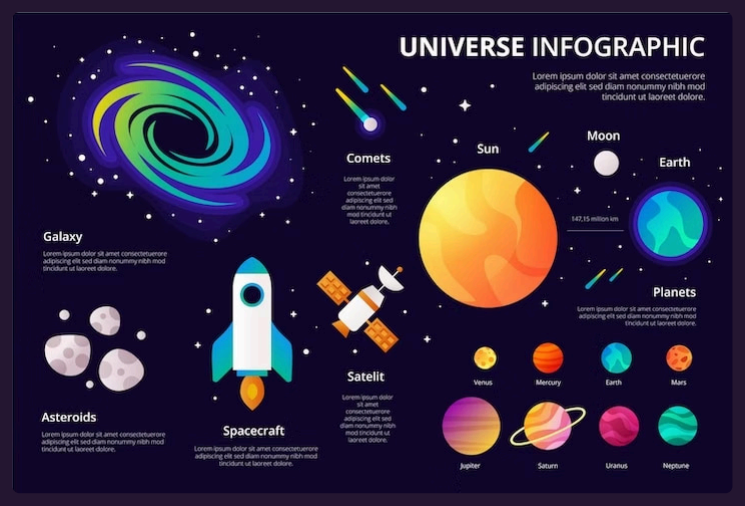
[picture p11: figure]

Stargazing = Experience

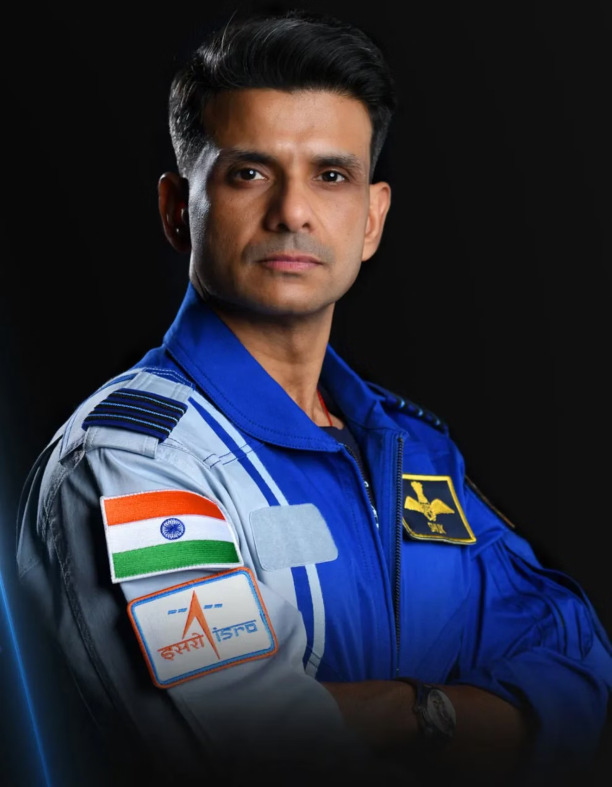
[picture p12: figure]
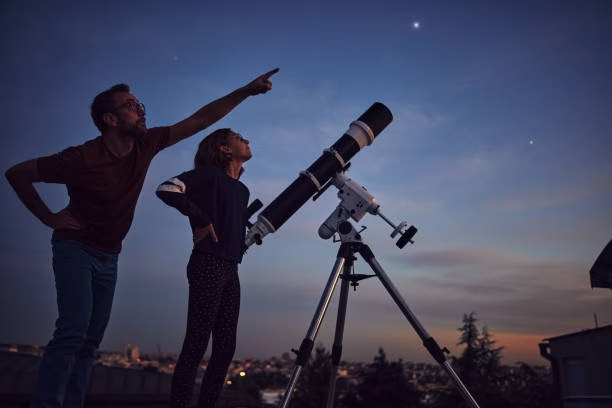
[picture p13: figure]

Shubhanshu Shukla is the 1st Indian astronaut to visit the International Space Station (ISS).
Total astronauts: 682
Indian astronauts: 2

# The Problem:

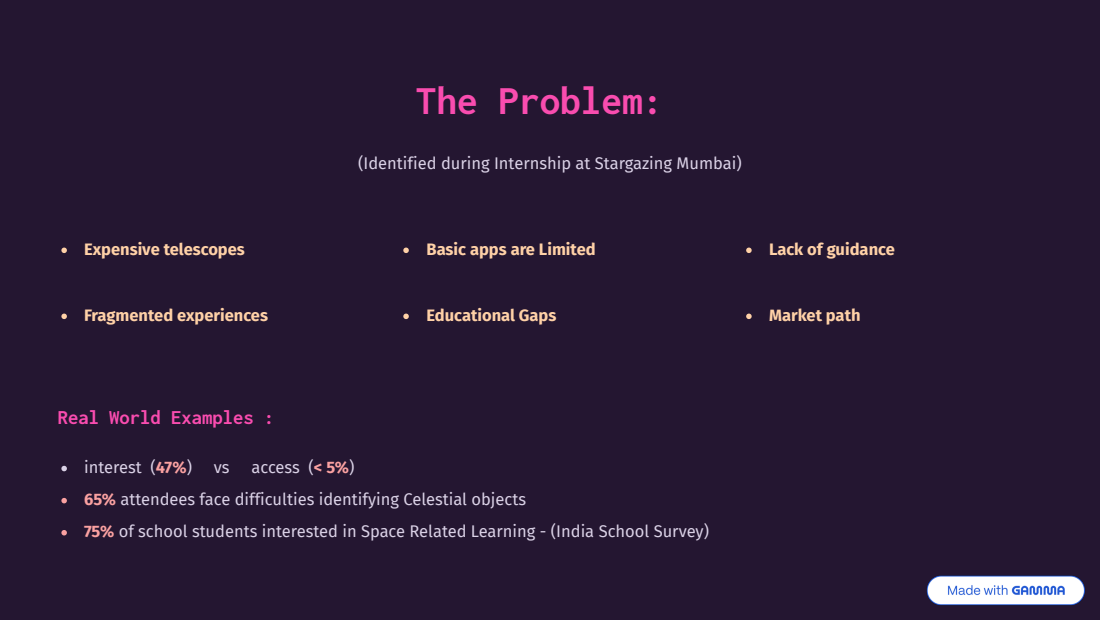
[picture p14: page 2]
Expensive telescopes; Basic apps are Limited; Lack of guidance; Fragmented experiences; Educational Gaps; Market path

(Identified during Internship at Stargazing Mumbai)

Real World Examples :

interest (47%) vs access (< 5%)
65% attendees face difficulties identifying Celestial objects
75% of school students interested in Space Related Learning - (India School Survey)

# Solution

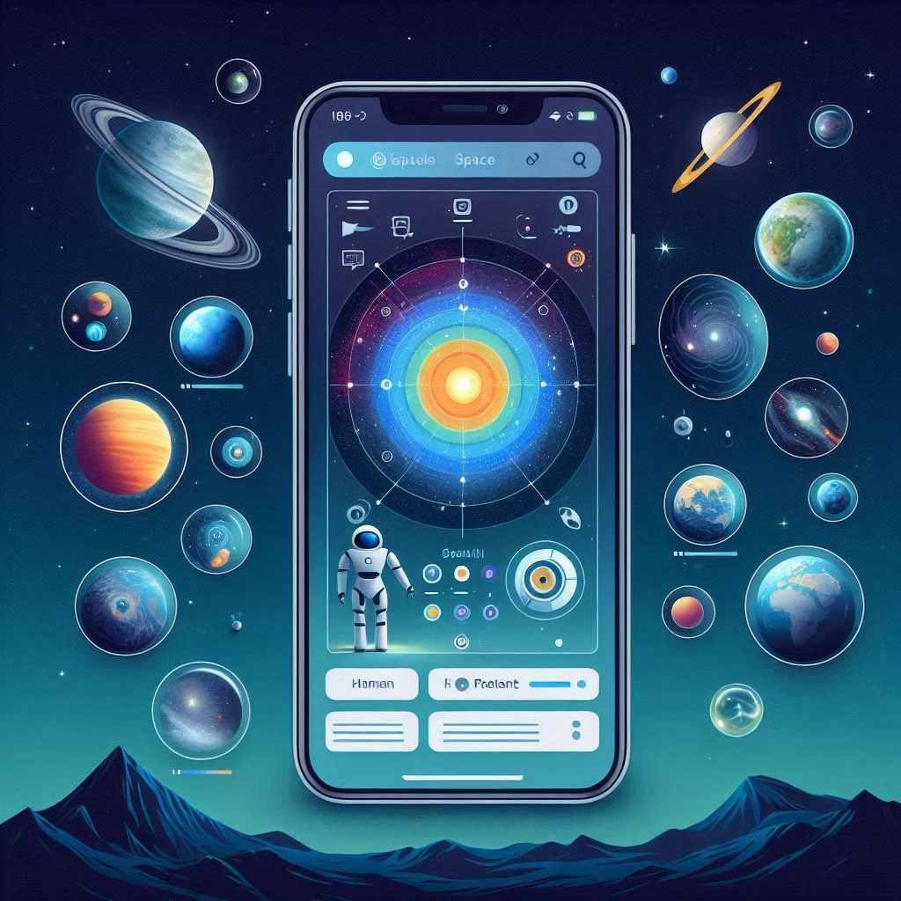
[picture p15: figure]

### StarStruck APP

Real time Live - Sky Map
Community collaboration
3D visuals
E3 Content
[ Education , Entertaining , Engaging ]

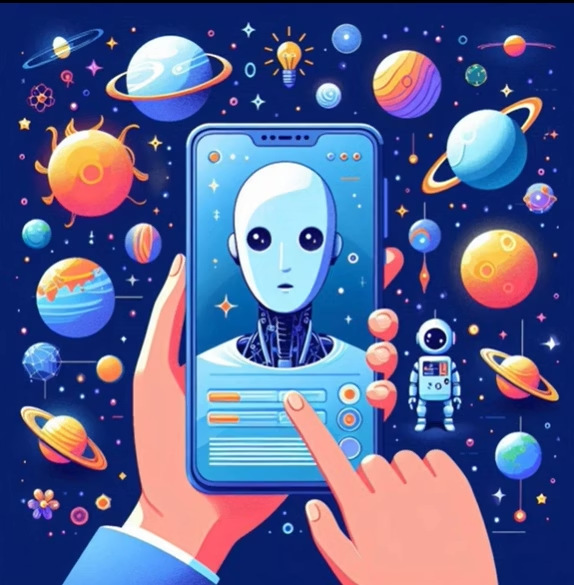
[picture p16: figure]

### AI Powered Guide

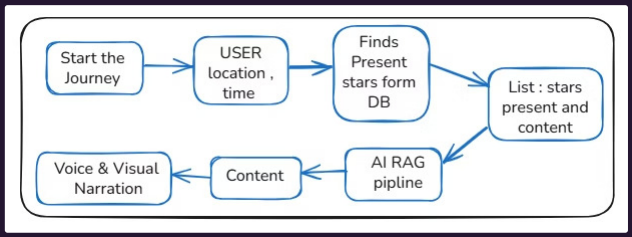
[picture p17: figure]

Astronomical Knowledge
Mythological Significance
Science ( Physics, Chemistry, Math ) Facts / Myths / More

# TaraScope device

Automated Celestial Navigation System for Stargazing events

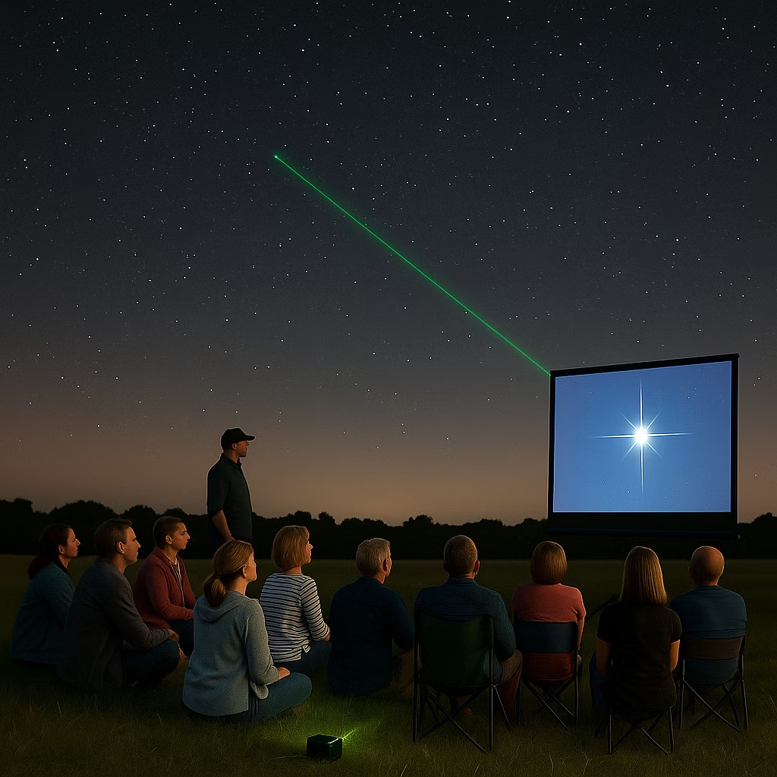
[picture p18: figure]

Star Navigation using Laser's Ray

Novel (No similar device present)

Accurate pointing using Advance Sensor Fusion Algorithms

Doesn't matter initial orientation of the device (Auto calibration)

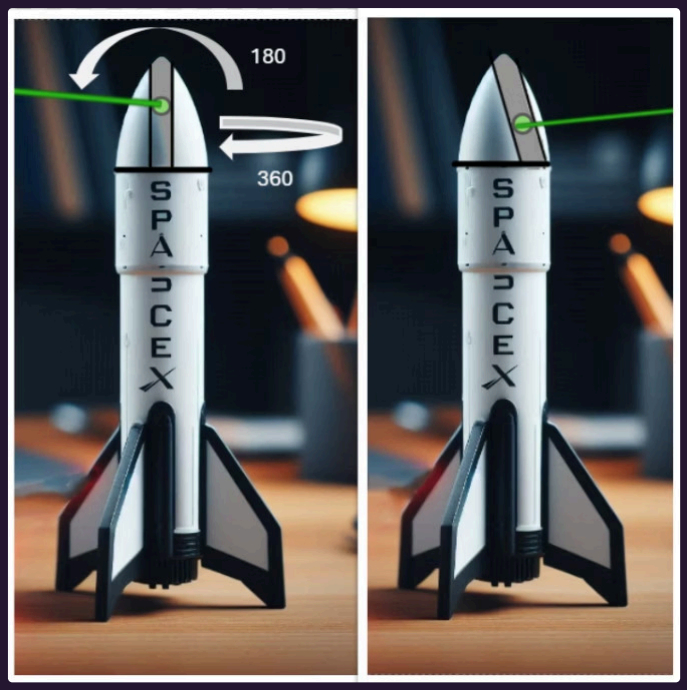
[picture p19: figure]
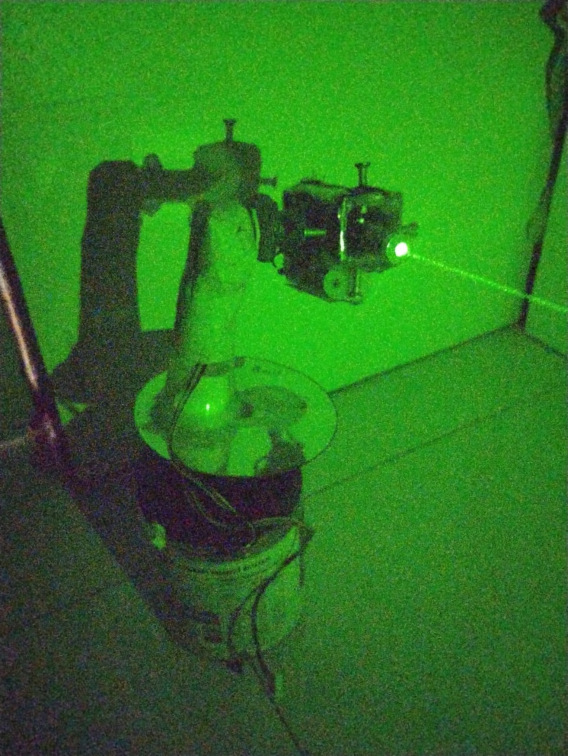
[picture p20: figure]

### 1. Concept

### 2. Prototype

### 3. Product

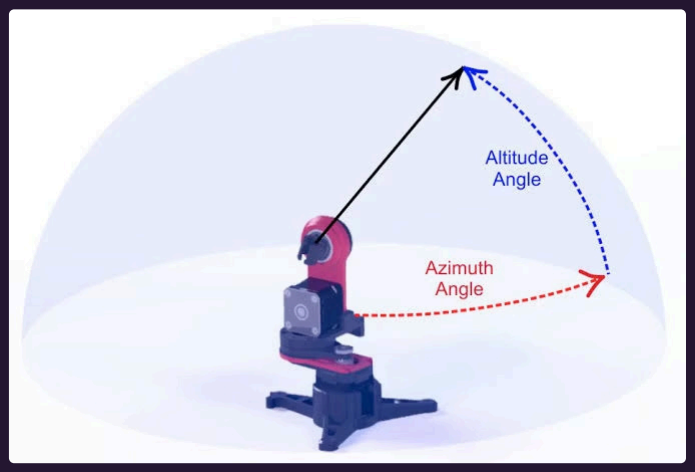
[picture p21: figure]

# Market Potential ¹50,000 Cr

### TAM

# ¹5,000 Cr

### SAM

# ¹250 Cr

### SOM

### Target Audience:
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

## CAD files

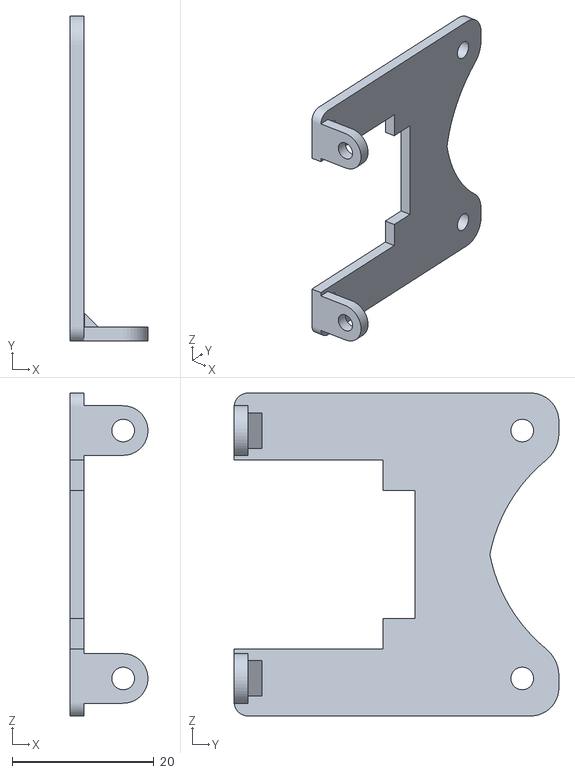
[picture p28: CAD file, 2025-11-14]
0_Components/3d_model/Joiner.stl
11.0 x 45.9 x 45.6

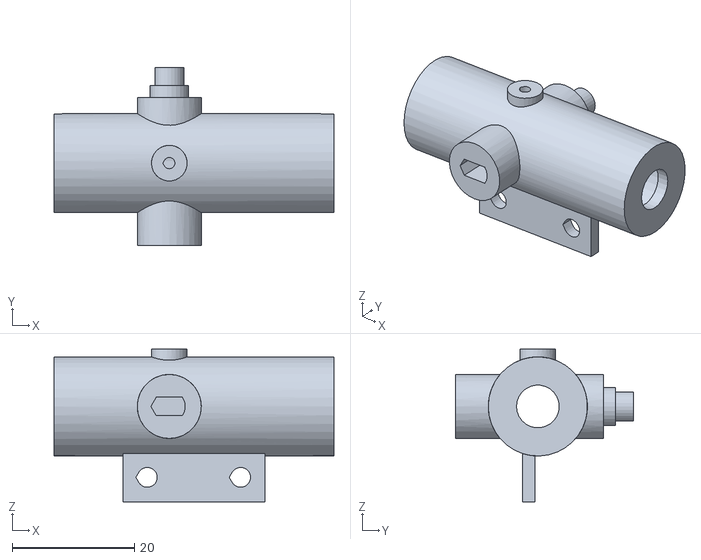
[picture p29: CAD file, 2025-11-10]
4_Stellector (study full)/Stellector-v0.1.0-alpha/jocoteles-Stellector-51ae170/horus/horus_3d_parts/laserCase.obj
45.9 x 29.2 x 25.0

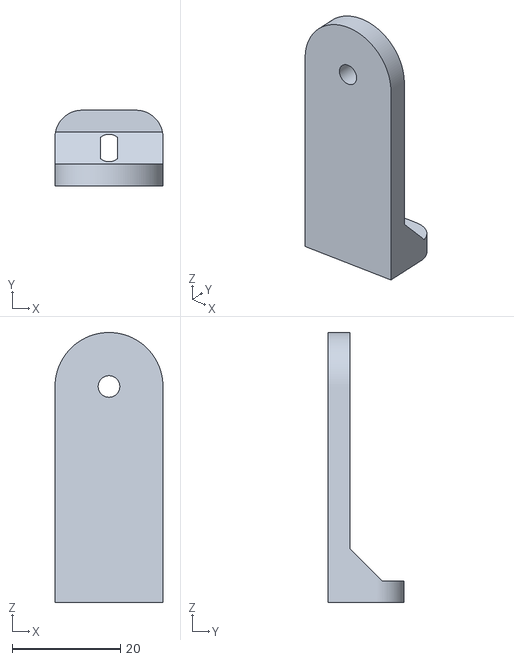
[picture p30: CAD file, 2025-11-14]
0_Components/3d_model/Camera_Mount.stl
20.0 x 14.0 x 50.0

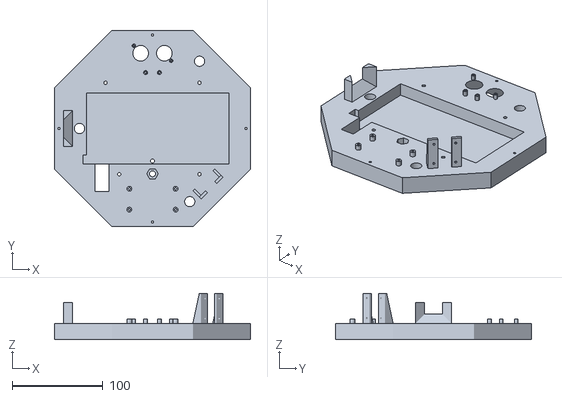
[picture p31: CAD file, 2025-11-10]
4_Stellector (study full)/Stellector-v0.1.0-alpha/jocoteles-Stellector-51ae170/horus/horus_3d_parts/octagonalBase.obj
215.5 x 215.5 x 51.0

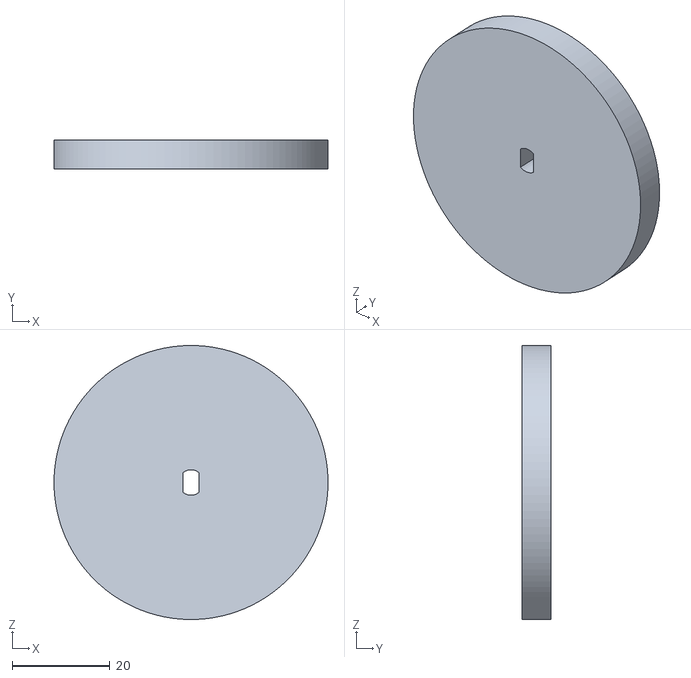
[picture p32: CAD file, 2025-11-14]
0_Components/3d_model/Base.stl
56.0 x 6.00 x 56.0

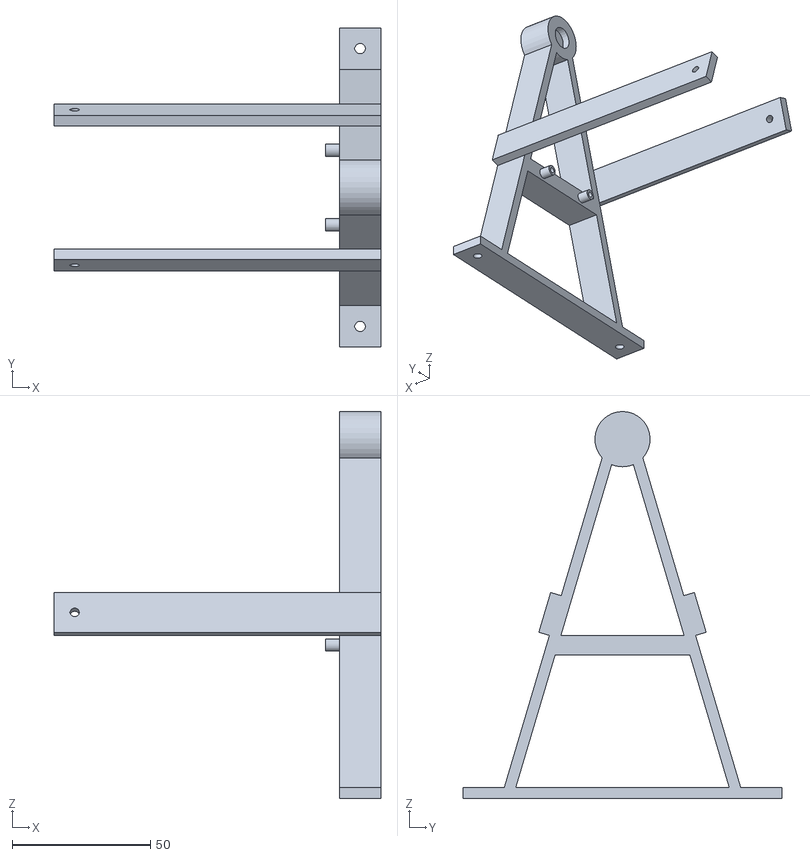
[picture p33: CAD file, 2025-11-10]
4_Stellector (study full)/Stellector-v0.1.0-alpha/jocoteles-Stellector-51ae170/horus/horus_3d_parts/towerBearing.obj
118.2 x 115.5 x 140.0

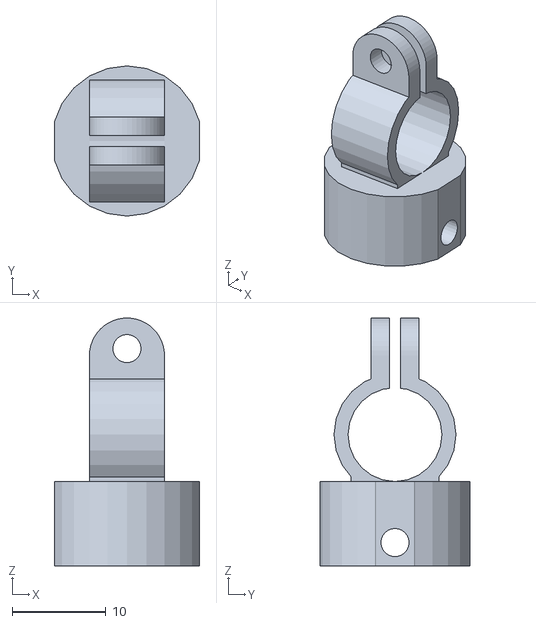
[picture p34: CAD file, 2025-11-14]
0_Components/3d_model/laserGimbalLaserMount.stl
15.5 x 16.0 x 26.4

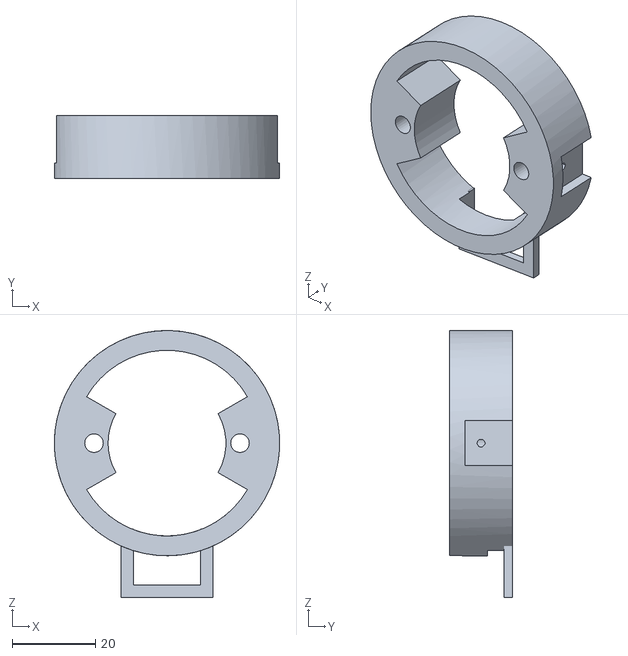
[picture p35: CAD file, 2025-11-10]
4_Stellector (study full)/Stellector-v0.1.0-alpha/jocoteles-Stellector-51ae170/horus/horus_3d_parts/stepperMob.obj
54.0 x 15.0 x 64.0

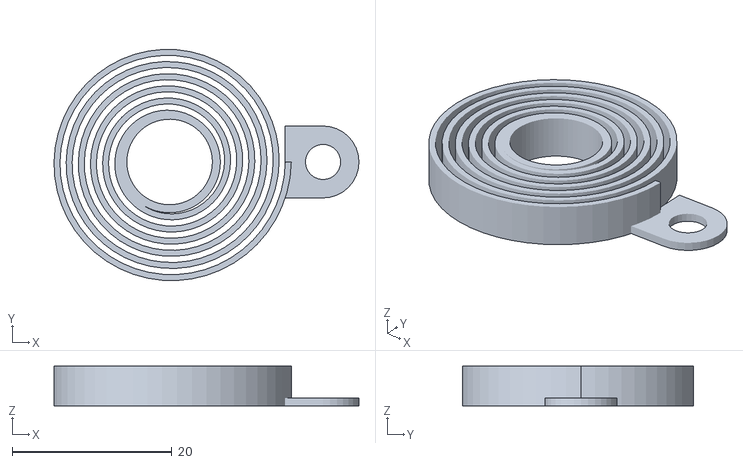
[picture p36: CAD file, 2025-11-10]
4_Stellector (study full)/Stellector-v0.1.0-alpha/jocoteles-Stellector-51ae170/horus/horus_3d_parts/spiralCoil_5v_p100.obj
38.2 x 28.9 x 5.00

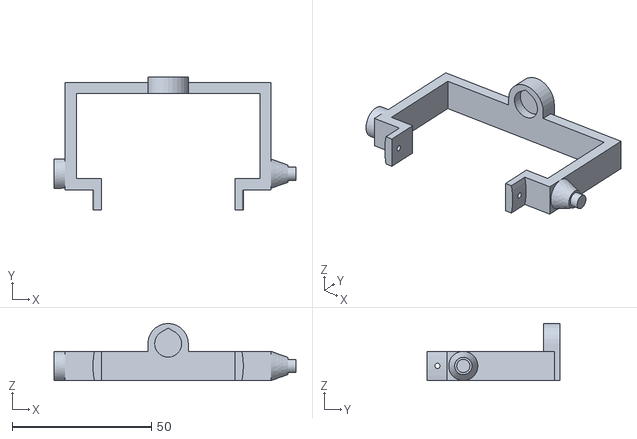
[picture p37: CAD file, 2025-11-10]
4_Stellector (study full)/Stellector-v0.1.0-alpha/jocoteles-Stellector-51ae170/horus/horus_3d_parts/laserShaftSupport.obj
86.9 x 47.8 x 20.5

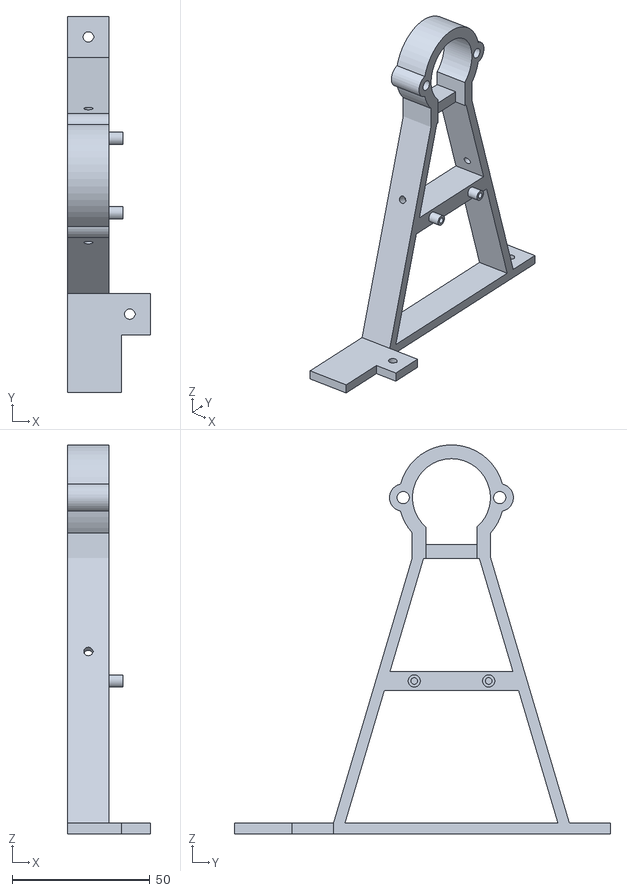
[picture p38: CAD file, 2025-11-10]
4_Stellector (study full)/Stellector-v0.1.0-alpha/jocoteles-Stellector-51ae170/horus/horus_3d_parts/towerStepper.obj
30.0 x 136.5 x 141.1

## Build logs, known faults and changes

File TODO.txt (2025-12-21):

1_calibration -> 1 week (sensor ka manual pdf read & code understand. 
                        My yellow_file read, Calib-YT-Guy video watch, calib code read, understand all, acc and gyro pehla full done kar,gyro calib, acc think what to do- my previous reading or new reading using motors,
                        write simple mag.py & mag.ino code for motor calib (see - calib using motor gpt) - last time the speed , etc was the issue - know more about it. also check how much influence the motor does on mag reading (by - motor contineously run karega, then sensor dur pas laa (run the Yaw wala code) , and see kitna degree farak padege)
                        so learn should it take contineous readings or stop and wait for 100ms to 1 sec and then take reading, since viration is also there after motor movement.  or if there is no impact of the motor - then parallely - move motor at x speed and take radings at y speed.)

2_sensor-fusion -> 1 week (full see and understand it, watch videos , use cpp code not python, since slow, write sf.ino code which reads raw values and gives nice RPY. )
// try esp32 if still slow RPY output.

3_laser -> Done

3_motor-code -> 3 days (easy) ( 2_pointing_concept par work, then write the 3_full-motor-code.ino which is basically mix of Sf.ino code ,  2_pointing_concept logic , and 1.2_manual_laser_pointing . )  checkout the arduino.txt file it has some logic.

4_star - pointing  -> 1 week (easy not a big deal, - 0 , 3 , 4 are easy . the main thing here is 1_star_calib and 2_use_offset - and this needs to be tested , iterated again and debugged- since yeahi say accuracy ayga . )

                    0_basic_pointing - use the ai-guide code to simply calculate the alt az and then send it to 3_full-motor-code .  see how much error , and why is this coming - figure out (if error is coming due to atmosphere,etc then it can be debugged using 3 star allignment, but if error due to something else - like sensor, or sf not accurate, or etc - then need to figure that out. )
                    1_star_calib - use the 0_basic_pointing code and controlled-by-button code to get the offset.
                    2_use_offset - same as 0_basic_pointing but now it gives alt az (after considering the offset) to the arudino
                    3_using_stellairium
                    4_main.py - so now - instead of doing mag calib , this , this , 3 star allignment - alag alag run file. we just simply run a single code file.
                    5_debug for accuracy - Rethink and make the pointing more accurate -> entire game of pointing Accuracy depends on -> 
                        * IMU sensor Accuracy (use better sensors, better calib),
                        * Get a Minimum Step Angle Motor , or use gear
                        * Accurate values calculate (ALT AZ) of a celestial object,
                        * Star alignment calibration. 
                        * etc stuff and technique - which can make poining more accurate.

// optional - 
// also need to study esp32 wrover , and how to share work with it - connection with sensors, i2c / uart , wireless seen - (Bluetooth / wifi) - (like can i share my code wirelessly or what ? , also using it for controlling -> sending commands , reading data/ values , etc )

5_destop app -> max 1 week -> see my written notes sheets - usme i have idea for the ui. and we can use 4_star_pointng code easily 

(first desktop app make then stellector study , since atleast i will have something to show for the vision. tarascope)

4_stellector study -> 1 week  full study.....  everything

6_intro website -> 1 week

7_documentation -> 1 week (each code file explain, write small research paper, working viedo make and put on yt)

8_Grant -> 1 week - make pitch deck , pitch video , think business , etc todo see and notes see. 

9_if-funded -> Gpt staragazer - read and think vision / ideate ( and be founder - and only focus to grow, and get team to build things)

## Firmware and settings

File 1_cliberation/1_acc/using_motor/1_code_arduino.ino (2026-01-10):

// here we use motor to print the data.
// it prints - average of 25 values (we are doing averaging here only in arduino, and not in py)
// and then in py - it just reads and scales the value and then store it.

////// ARD_code_1 -> using single motor (single axis sensor rotation) (you need to manually change the next orientation and again press "s")
/////  ARD_code_2 -> using 2 motors (3 axis sensor rotation) (you only need to press "s" once)







// ###################################################### ARD_CODE_1 ######################################################

#include <Wire.h>
#include "SparkFun_ISM330DHCX.h"
#include <CheapStepper.h>

SparkFun_ISM330DHCX myISM;
sfe_ism_raw_data_t rawAccel;

CheapStepper motorAlt(4, 5, 6, 7);

// IMP - so that loop run as per the data rate of sensor and not try to run as fast as possible 
unsigned int DataRate_HZ;	
unsigned long PERIOD_US;          
// time tracker for loops -> mainLoop(), while() , for()     
unsigned long lastRead = 0; 
unsigned long now = 0;


// #######################   CONFIG   ####################### 
#define AVG_MEAS  25 // take Avg of N readings to get 1 stable reading /per orientation.
const int STEPS_PER_REV = 4096;
const int N_orientations = 32 ;
//SET THIS //(value must be -> 2^N). [VALUES -> (1 = 360Deg) (2 = 180Deg) (4 = 90Deg) (8 = 45Deg) (16 = 22.5Deg) (32 = 11.25Deg) (64 = 5.625Deg) (128 = 2.8125Deg) (256 = 1.4Deg)]
const int STEPS_to_move_per_orientation = (STEPS_PER_REV / N_orientations) ;
// So if 4096/1_orientation => so 4096_steps_per_orientation to complete 1 full rotation. if 4096/2_orientaitons => so 2048_step)per_orientation and it will take 2 orientatins to complete 1 full rotation.      
// #############################################################

int count = 0; // iterator for Average readings
long ax = 0, ay = 0, az = 0; // Make Avg calculation 0 - before storing new avg calculations.

// function to calculte the avg readings and print it.
void Read_Accel_data()
{
  // take 25 readings ka AVG - for single orientation.
    now = 0;
    lastRead = 0;
    count = 0; // make iterator 0 before starting.
    ax = 0; ay = 0; az = 0; // Make Avg calculation 0 - before storing new avg calculations.
    while (count < AVG_MEAS)  // dont worry it will take N readings as per AVG_MEAS at 104/particual hz.
    {
        now = micros();
        if (now - lastRead >= PERIOD_US)
        {
            lastRead = now;
            if(myISM.getRawAccel(&rawAccel))
            {
                ax += rawAccel.xData;
                ay += rawAccel.yData;
                az += rawAccel.zData;
                count++;
            }
        }
    }

    // find AVG
    ax /= AVG_MEAS;
    ay /= AVG_MEAS;
    az /= AVG_MEAS;

    // Send AVG RAW LSB ONLY , and in python it will scale
    Serial.print(ax);
    Serial.print(",");
    Serial.print(ay);
    Serial.print(",");
    Serial.println(az);
}


void setup()
{
  Wire.begin();
  Serial.begin(115200);

  if (!myISM.begin()) {
	Serial.println("Could not initialize ISM330DHCX. Check connections.");
    while (1);
  }
	
  // Reset the device to default settings
  myISM.deviceReset();
  while (!myISM.getDeviceReset()) {
	delay(1);
  }
  Serial.println("Reset complete.");
  Serial.println("Applying settings.");
  delay(100);

    // Apply device settings
    myISM.setDeviceConfig();
    myISM.setBlockDataUpdate(); 
	
	// Wire.setClock(400000); // uncomment it if using 416hz or higher data rate , other wise comment it.

  // Range -> always need to set, even if scaling maunally
	myISM.setAccelFullScale(ISM_2g); 
	// test: in Motor_code if motor moves faster than 2g or 125dps then the sensor values can break - so in that senario we can do 4g or 250dps, but that can lower the precision. other jugad we can do is -> move motor slowly or etc.
	// if you wanna update the range of acc or gyro then - not just you have to change the scaling factor , but again calib (as per that_range_lsb_data * that_range_scaling_factor) and get new offset.


	// DataRate -> 104Hz is good (fast & low noise) // can also try 208 or more in SF since it needs frequent values.
	myISM.setAccelDataRate(ISM_XL_ODR_104Hz); // data rate (best -> 104, 208, 416) (for faster use -> 833, 1666, 3332, 6667) (for slower use -> 52, 26, 12Hz5, 1Hz6 )
	DataRate_HZ = 104; // keep same as sensor_Hz
  PERIOD_US = (1000000UL / DataRate_HZ); // using this we Control the iteration time.

	// Filter ->
	myISM.setAccelFilterLP2(false); // can keep it ON also, // later, TRY : ON in SensorFusion and see the results. 
    // myISM.setAccelSlopeFilter(ISM_LP_ODR_DIV_20); // can keep 20, 45 (not 10) // (if you keep the filter then based on the filter -> update the hardcoded offset/bias as per that)
	
	// fifo config (not much to do here, can try stream mode in SF, see 1_full_info.ino ka final setting section for more info)
	myISM.setFifoMode(ISM_BYPASS_MODE); // fifo off (default)
	
    
  motorAlt.setTotalSteps(STEPS_PER_REV);
  motorAlt.setRpm(10); // 6 to 24


	delay(100);
  Serial.println("Settings applied.");

}



void loop() {
  if (Serial.available()) {
    char cmd = Serial.read();

    if (cmd == 's') {
      Serial.println("START");
      delay(1000);

      // Moves N times to complete 360 degree. 
      for (int i = 0; i < N_orientations ; i++)  // take reading for full circle - 
      { 
        if(i == 0)
        {
          delay(2000); // keep
          Read_Accel_data(); // initail read before moving the motor (since it moves the motor first and then reads)
        }

        delay(200); // keep
        motorAlt.move(true, STEPS_to_move_per_orientation); // move to next orientation of current movement.
        delay(2000); // 2 sec delay to stabalize the vibration, after motor has moved to the new position.
        Read_Accel_data();
      }

      delay(1000);
      motorAlt.move(false, STEPS_PER_REV ); // return to inital position of Movement 1


      Serial.println("DONE");
      Serial.println(STEPS_PER_REV);
      Serial.println(N_orientations);
      Serial.println(STEPS_to_move_per_orientation);
  }


    if (cmd == 'q') {
      Serial.println("QUIT");
      while (1);
    }
  }
}






// ###################################################### ARD_CODE_2 ######################################################




#include <Wire.h>
#include "SparkFun_ISM330DHCX.h"
#include <CheapStepper.h>

SparkFun_ISM330DHCX myISM;
sfe_ism_raw_data_t rawAccel;

CheapStepper motorAlt(4, 5, 6, 7);
CheapStepper motorAz(8, 9, 10, 11);

// IMP - so that loop run as per the data rate of sensor and not try to run as fast as possible 
unsigned int DataRate_HZ;	
unsigned long PERIOD_US;          
// time tracker for loops -> mainLoop(), while() , for()     
unsigned long lastRead = 0; 
unsigned long now = 0;

// #######################   CONFIG   ####################### 
#define AVG_MEAS  25 // take Avg of N readings to get 1 stable reading /per orientation.
const int STEPS_PER_REV = 4096;
const int N_orientations = 64 ;
//SET THIS //(value must be -> 2^N). [VALUES -> (1 = 360Deg) (2 = 180Deg) (4 = 90Deg) (8 = 45Deg) (16 = 22.5Deg) (32 = 11.25Deg) (64 = 5.625Deg) (128 = 2.8125Deg) (256 = 1.4Deg)]
const int STEPS_to_move_per_orientation = (STEPS_PER_REV / N_orientations) ;
// So if 4096/1_orientation => so 4096_steps_per_orientation to complete 1 full rotation. if 4096/2_orientaitons => so 2048_step)per_orientation and it will take 2 orientatins to complete 1 full rotation.      
// #############################################################

int count = 0; // iterator for Average readings
long ax = 0, ay = 0, az = 0; // Make Avg calculation 0 - before storing new avg calculations.

// function to calculte the avg readings and print it.
void Read_Accel_data()
{
    // take 25 readings ka AVG - for single orientation.
    now = 0;
    lastRead = 0;
    count = 0; // make iterator 0 before starting
    ax = 0; ay = 0; az = 0; // Make Avg calculation 0 - before storing new avg calculations.
    while (count < AVG_MEAS)  // take Multiple readings ka AVG - for single orientation - at particular Hz.
    {
        now = micros();
        if (now - lastRead >= PERIOD_US)
        {
            lastRead = now;
            if(myISM.getRawAccel(&rawAccel))
            {
                ax += rawAccel.xData;
                ay += rawAccel.yData;
                az += rawAccel.zData;
                count++;
            }
        }
    }

    // find AVG
    ax /= AVG_MEAS;
    ay /= AVG_MEAS;
    az /= AVG_MEAS;

    // Send AVG RAW LSB ONLY , and in python it will scale
    Serial.print(ax);
    Serial.print(",");
    Serial.print(ay);
    Serial.print(",");
    Serial.println(az);
}


void setup()
{
  Wire.begin();
  Serial.begin(115200);

  if (!myISM.begin()) {
	Serial.println("Could not initialize ISM330DHCX. Check connections.");
    while (1);
  }
	
  // Reset the device to default settings
  myISM.deviceReset();
  while (!myISM.getDeviceReset()) {
	delay(1);
  }
  Serial.println("Reset complete.");
  Serial.println("Applying settings.");
  delay(100);

    // Apply device settings
    myISM.setDeviceConfig();
    myISM.setBlockDataUpdate(); 
	
	// Wire.setClock(400000); // uncomment it if using 416hz or higher data rate , other wise comment it.

	
	// DataRate -> 104Hz is good (fast & low noise) // can also try 208 or more in SF since it needs frequent values.
	myISM.setAccelDataRate(ISM_XL_ODR_104Hz); // data rate (best -> 104, 208, 416) (for faster use -> 833, 1666, 3332, 6667) (for slower use -> 52, 26, 12Hz5, 1Hz6 )
	DataRate_HZ = 104; // keep same as sensor_Hz
    PERIOD_US = (1000000UL / DataRate_HZ); // using this we Control the iteration time.

    // Range -> always need to set, even if scaling maunally
	myISM.setAccelFullScale(ISM_2g); 
	// test: in Motor_code if motor moves faster than 2g or 125dps then the sensor values can break - so in that senario we can do 4g or 250dps, but that can lower the precision. other jugad we can do is -> move motor slowly or etc.
	// if you wanna update the range of acc or gyro then - not just you have to change the scaling factor , but again calib (as per that_range_lsb_data * that_range_scaling_factor) and get new offset.
	
  
	// Filter ->
	myISM.setAccelFilterLP2(false); // can keep it ON also, // later, TRY : ON in SensorFusion and see the results. 
    // myISM.setAccelSlopeFilter(ISM_LP_ODR_DIV_20); // can keep 20, 45 (not 10) // (if you keep the filter then based on the filter -> update the hardcoded offset/bias as per that)
	myISM.setGyroFilterLP1(false); // strictly off
	
	// fifo config (not much to do here, can try stream mode in SF, see ISM/1_full_info.ino ka final setting section for more info)
	myISM.setFifoMode(ISM_BYPASS_MODE); // fifo off (default)

  // set motor RPM (10 is good)  
  motorAlt.setTotalSteps(STEPS_PER_REV);
  motorAlt.setRpm(10); // 6 to 24
  motorAz.setTotalSteps(STEPS_PER_REV);
  motorAz.setRpm(10); // 6 to 24

	delay(100);
  Serial.println("Settings applied.");

}



void loop() {
  if (Serial.available()) {
    char cmd = Serial.read();

    if (cmd == 's') 
    {
      Serial.println("START");
      delay(1000);

      //////////////////////////// MOVEMENT 1 -> Alt motor full rotation - from Initial orientation
      for (int i = 0; i < N_orientations ; i++)  // take reading for full circle - 
      { 
        if(i == 0)
        {
          delay(2000); // keep
          Read_Accel_data(); // initail read before moving the motor (since it moves the motor first and then reads)
        }

        // first Motor-move and then take readings.
        delay(200); // keep
        motorAlt.move(true, STEPS_to_move_per_orientation); // move to next orientation of current movement.
        delay(2000); // 2 sec delay to stabalize the vibration, after motor has moved to the new position.
        Read_Accel_data();
      }

      delay(1000);
      motorAlt.move(false, STEPS_PER_REV ); // return to inital position of Movement 1


      ////////////////////////// Movement 2 -> AZ motor full rotation - From initial orientation. 
      for (int i = 0; i < N_orientations ; i++)  
      { 
        if(i == 0)
        {
          delay(2000); // keep
          Read_Accel_data(); 
        }
        
        delay(200); // keep
        motorAz.move(false, STEPS_to_move_per_orientation); // move to next orientation of current movement. using AZ motor .
        delay(2000); // 2 sec delay to stabalize the vibration, after motor has moved to the new position.
        Read_Accel_data();
      }

      // no need to return to initial posi now, we first go to movement3 starting position.
      delay(1000);
      motorAlt.move(true, (STEPS_PER_REV/4)); // Rotate alt motor +90 deg.

      ////////////////////////////////// Movement 3 -> Rotate alt motor by 90 deg or 4096/4, then AZ motor full rotation in opposite direction this time.
      for (int i = 0; i < N_orientations ; i++) 
      { 
        if(i == 0)
        {
          delay(2000); // keep
          Read_Accel_data(); 
        }

        delay(200); // keep
        motorAz.move(true, STEPS_to_move_per_orientation); // move to next orientation of current movement. Using AZ motor (opposite this time)
        delay(2000); 
        Read_Accel_data();
      }
      delay(1000);
      motorAlt.move(false, (STEPS_PER_REV/4)); // move the alt motor back to -90 degree (back to inital orientation)
      // So now we are OG back to OG inital orientation.
      
      delay(2000);
      Read_Accel_data(); // final read - just to check if we are where we started from (green / red dot on plot) // no need to check in 8_Auto_calib.

      Serial.println("DONE");
      Serial.println(STEPS_PER_REV);
      Serial.println(N_orientations);
      Serial.println(STEPS_to_move_per_orientation);
    }

    if (cmd == 'q') {
      Serial.println("QUIT");
      while (1);
    }
  }
}

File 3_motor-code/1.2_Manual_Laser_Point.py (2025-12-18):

# Arrow keys = fast movement
# w a s d = precise movement
# SPACE = laser toggle 
# f = fade laser 
# v = draw diamond
# c = draw circle 
# b = draw box / square
# ESC = quit

# (not tested the laser part yet, need to check after doing 3_laser part)

# after laser code done, update here also. 

# Test out the radius and speed(delay) in arduino code. - and see if proper circeling out the star. 
# keep the values as mentioned for radius and delay . try to lower the radius and increase the delay to see how it impacts the circle shape.

# circle is not properly coming with smaller radius, you have to update stepDeg = 1 - 5 accordingly. (jitna bada Radius unta chota stepDeg, and vice versa)

# // place alt motor on the left side (facing right) of of the az mount , and laser will point forward .


##############################################################################################

# // Arduino code 

# #include <CheapStepper.h>

# // AZ - left (false) right (true)
# // Alt - up (false) down (true)


# // -------- Motors --------
# CheapStepper motorB(4, 5, 6, 7);     // Altitude (ULN2003 IN1–IN4)
# CheapStepper motorA(8, 9, 10, 11);   // Azimuth (ULN2003 IN1–IN4)

# const long STEPS_PER_REV = 4076;
# const int RPM = 10;  // base RPM for normal moves

# // ===== PRECISE CONTROL SETTINGS (w a s d) =====
# const int PRECISE_STEP  = 1;     // steps per precise press  // keep it 1


# // ===== Shape settings #################################################################################
# const int RADIUS_IN_STEPS = 5;      // <- radius (steps) // keep 20 . below 10 dosent work
# const int DELAY_MS = 200;       // <- speed (ms per iteration) // keep 50 . 
# // both are inversely proportional - so if you increase the Radius then decrease the delay ex - 200 Radius , 5 delay.
# // and if you want to decrease the Radius then decrease the delay. ex - 15 Radius , 60 delay.
# // ######################################################################################################

# // -------- Laser - spacebar - on/off --------
# #define LASER_PIN 3   // PWM pin we can use this pin for both - digitalWrite and analogWrite
# bool laserOn = false; 

# void setLaser(bool on) { 
#   laserOn = on;
#   digitalWrite(LASER_PIN, on ? HIGH : LOW);
# }

# // -------- Laser fade - --------
# const int FADE_RATE_MS = 15;      // delay between fade steps
# const int LASER_ON_TIME_MS = 200; // how long laser stays ON at full brightness

# void fadeLaser(int fadeRate, int laserOnTime) {
#   Serial.println("Laser fade: starting");

#   // 1) Fade In
#   for (int brightness = 0; brightness <= 255; brightness++) {
#     analogWrite(LASER_PIN, brightness);
#     delay(fadeRate);
#   }

#   // 2) Hold full brightness
#   delay(laserOnTime);

#   // 3) Fade Out
#   for (int brightness = 255; brightness >= 0; brightness--) {
#     analogWrite(LASER_PIN, brightness);
#     delay(fadeRate);
#   }

#   analogWrite(LASER_PIN, 0);
#   Serial.println("Laser fade: done");
# }

# void setup() {
#   pinMode(LASER_PIN, OUTPUT);
#   setLaser(false); // start OFF

#   Serial.begin(9600);

#   motorA.setTotalSteps(STEPS_PER_REV);
#   motorB.setTotalSteps(STEPS_PER_REV);

#   motorA.setRpm(RPM);
#   motorB.setRpm(RPM);

# }

# // ------------------------ Shapes ------------------------

# inline void stepBoth(bool azDir, bool altDir) {
#   motorA.move(azDir, 2);
#   motorB.move(altDir, 1);
#   delay(DELAY_MS);
# }

# void drawDiamond() {

#   Serial.println("Drawing Diamond..."); 

#   // long alt0 = motorB.getStep();  // no need of this, since we are not using moveTo() to return to the original posi. // but still keep the code.
#   // long az0  = motorA.getStep();


#   // 1) go to bottom (ALT down by R)
#   for(int i=0;i<RADIUS_IN_STEPS;i++) {
#     motorB.move(true, 1);
#     delay(DELAY_MS);
#   }  
#   delay(500);

#   // 2) laser ON
#   setLaser(true);

#   // 3) four loops 

#   // Loop1: AZ left R, ALT up R
#   for(int i=0;i<RADIUS_IN_STEPS;i++) stepBoth(false, false);

#   // Loop2: AZ right R, ALT up R
#   for(int i=0;i<RADIUS_IN_STEPS;i++) stepBoth(true,  false);

#   // Loop3: AZ right R, ALT down R
#   for(int i=0;i<RADIUS_IN_STEPS;i++) stepBoth(true,  true);

#   // Loop4: AZ left R, ALT down R
#   for(int i=0;i<RADIUS_IN_STEPS;i++) stepBoth(false, true);

#   // 4) laser OFF
#   setLaser(false);

#   delay(500);

#   // 5) return to original pointing

#     for(int i=0;i<RADIUS_IN_STEPS;i++) {
#     motorB.move(false, 1);
#     delay(DELAY_MS);
#   }  

#   // #   motorB.moveTo(false, alt0); // up 
#   // // ---- Smart Azimuth return ---- we cannot simply do motorA.moveTo(az0) because it may take the long way around
#   // long currentAz = motorA.getStep();
#   // long diff = az0 - currentAz;
#   // if (diff > 0)      motorA.moveTo(true,  az0);
#   // else if (diff < 0) motorA.moveTo(false, az0);

#   delay(200);
#   Serial.println("Diamond done");
# }

# //-------------------------------------------------
# void drawSquare() {
#   Serial.println("Drawing Square...");

#   // long alt0 = motorB.getStep();
#   // long az0  = motorA.getStep();

#   for(int i=0;i<RADIUS_IN_STEPS;i++) {
#     motorB.move(true, 1);
#     delay(DELAY_MS);
#   } 
#     delay(500);

#   setLaser(true);

# // 3) Left by R/2
#   for (int i = 0; i < RADIUS_IN_STEPS ; i++) {
#     motorA.move(false, 1);   // left
#     delay(DELAY_MS);
#   }

#   // 4) Up by R
#   for (int i = 0; i < RADIUS_IN_STEPS * 2; i++) {
#     motorB.move(false, 1);   // up
#     delay(DELAY_MS);
#   }

#   // 5) Right by R
#   for (int i = 0; i < RADIUS_IN_STEPS * 2; i++) {
#     motorA.move(true, 1);    // right
#     delay(DELAY_MS);
#   }

#   // 6) Down by R
#   for (int i = 0; i < RADIUS_IN_STEPS * 2; i++) {
#     motorB.move(true, 1);    // down
#     delay(DELAY_MS);
#   }

#   // 7) Left by R/2 
#   for (int i = 0; i < RADIUS_IN_STEPS ; i++) {
#     motorA.move(false, 1);   // left
#     delay(DELAY_MS);
#   }

#   setLaser(false);
#   delay(500);

#   // return to original center
  
#   for(int i=0;i<RADIUS_IN_STEPS;i++) {
#     motorB.move(false, 1);
#     delay(DELAY_MS);
#   }  

#   // #   motorB.moveTo(false, alt0); // up 
#   // long currentAz = motorA.getStep();
#   // long diff = az0 - currentAz;
#   // if (diff > 0)      motorA.moveTo(true,  az0);
#   // else if (diff < 0) motorA.moveTo(false, az0);

#   delay(200);

#   Serial.println("Square done");
# }

# //-------------------------------------------------

# void drawCircle() {

#   Serial.println("Drawing Circle...");
  
#   // long alt0 = motorB.getStep();
#   // long az0  = motorA.getStep();

#   const float stepDeg = 2; // smaller = smoother // jitna small Radius utna hee bada stepDeg rakhna padega.

#   // move to bottom of circle
#   for(int i=0;i<RADIUS_IN_STEPS;i++) {
#     motorB.move(true, 1);
#     delay(DELAY_MS);
#   } 
#   delay(500);

#   setLaser(true);

#   float prevAz = 0;
#   float prevAlt = -RADIUS_IN_STEPS; // start at bottom
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

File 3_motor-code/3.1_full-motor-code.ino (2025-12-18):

// so basically - an alt az values is given from terminal, and then it calculates the rpy using sensors and S.F. (use the sf_code for this part)
// then it moves the motors to make pitch = alt and yaw = az .  (use the 2_Pointing_concept for the pointing part)
// and then when reached the target alt az , it does some laser action - or just simply points to it. and then we can do laser toggle uins spacebar or draw shape, etc or move motors , etc... ( use the 1.2_manual_laser_code for this part)
// i know that it will not point accurately since we are not using by lets try . and this code will be very usefull for star_Pointing codes . 
// before starting this code - first full figure out the sf code , and 2_pointing_concept code (like parallel move motors , or what , and etc concepts....)
// so the arduino calculates the rpy using sf code. and it Always waits for inputs - such as 
// if P is pressed in vs code terminal then it asks for alt az values and after we press enter - it send it to arduino and the arduino code points to that alt az.  and it now contineously points to that alt az until a new raading is given
// if O is pressed in vs code terminal then it goes to default mode of pointing 0,0 alt az .
// and if I is pressed then it shows the current rpy values in terminal. (avg of 10 readings, etc)
// and baki sab 1.2_manual_laser_code functions -> fast slow move, laser toggle , draw shapes , etc can be done after reaching the target alt az.
// and the alt az we will manually type it from sterellium mobile app for now. and in the  4_star_poinint we will use own libary or sterellium desktop app simply. and send that alt az values to arudino)

// so first we give a targeted ALT AZ - hardcode (alt = 0 , az = 0) 
// then A) the rpy is calculated using sensors and S.F. (use the arduino_rpy_read code)
// then B) the motor move some steps to make the pitch and yaw 0 . ( use the motor_concept)
// and this works in a loop -> A)read sensor -> calc rpy -> B)move motor by this much steps -> A) ... do this again . and thats how reach a target posi.
// and move motors like -> parallel move // or first yaw then pitch // or alternative pitch the yaw then pitch the yaw // ... think on this
// so, default it will point to 0 , 0 degrees alt az .

// Also the arduino scripts always reads the serial monitor for inputs. if there is no input then the above A)B)A)B)... 
//  but if input aya using -> injesting a Target ALT AZ value using serial monitor from a .py script.
// then the motor move to make the Pitch equal to Alt and/ yaw equal to Az. 
// and it does that in a loop A)B)A)B) and when reached the target then laser will on. 
// and it will keep pointing to that target alt az until a Particular key is not pressed "0" (default)  in the terminal. 
// and after '0' is pressed , it will again go to default mode of pointing 0,0 alt az.
// then again if a new target alt az is given from terminal , it will point to that. 

// need to write differnt functions for - 0,0 default pointing , and target alt az pointing. (since in target alt az pointing - after reaching the target - laser function is called on etc ...)


// combine Motor_concept.ino code and RPY code . 


// its not easy , since the sensor fetch data and takes time and motor movement will also take time, 
// and it's all wirtten inloop so gonna be a mess . 
//serial.begin seen etcc ....

// we can then also do like - laser toggle , or draw shapes , fade , etc. and after that action is done, the motor auto comes to the initial position using moveTo(starting) (which is basically the target alt az approx) and after that funciton is done - then the main code runs which moves the motors to the target alt az, that we gave it.





// Entire flow likh : -----------------------------------------------

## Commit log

2025-11-10 inital commit
    [Parameters.txt, laserCase.obj, laserShaftSupport.obj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]
2025-11-10 new commit
    [laserCase.obj, laserShaftSupport.obj, octagonalBase.obj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]
2025-11-14 new updates in ideas
    [Base.stl, Camera_Mount.stl, Joiner.stl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]
2025-11-17 Add demo video links to README
    Added links to demo videos for the automatic stargazing device.
2025-12-23 acc calibrated
2025-12-30 new code updates - in calibration
2025-12-30 renamed the gyro folder
2025-12-30 renamed the gyro folder in gitignore
2026-01-01 gyro calib done, acc calib also done
    [connections.fzz]
2026-01-08 interrupt coded
2026-01-10 working on final/Auto_calib codes
    [connections.fzz]
2026-01-14 final/Auto_calib code done - using accel / gyro . mag is still remaining
